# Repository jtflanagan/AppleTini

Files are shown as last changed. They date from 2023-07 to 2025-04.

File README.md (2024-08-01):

# AppleTini
An FPGA-based multifunctional card

Earlier iterations of the design used microcontrollers (a Pico and a Teensy 4.1), but we have moved to an FPGA-based design.  The v4 version of the board works in an Apple IIe as a read-only bus dump card.  It reads events on the Apple II bus, and forwards them over USB to a remote host which can process them (including operating as HDMI video-out, similar to the VidHD card).

The v5 board (just ordered!) is intended to provide the full bus feature set.  The ability to read and write data to the bus, as well as perform full DMA and assert all the control lines available (DMA, RES, RDY, INH, IRQ, NMI, and properly implement DMAIN/OUT and INTIN/OUT.

The boards are designed to connect to a stack of Alchitry boards as sold by SparkFun.  The boards have headers which will mate with the Alchitry Br breakout board.  The high-speed USB needed to do bus dumping is provided by the Alchitry Ft board, which is capable of up to 1.6Gbits/sec data transmit over USB3.  The FPGA, and 256MB of DDR3 SDRAM is provided by the Alchitry Au board.

What can this board ultimately do?  Damn near anything.  Shorter term goals are to provide HDMI out, speaker sound, Mockingboard sound, mouse, Ramworks or Slinky style memory expansion, and solid state HDV storage.  Longer term?  CPU Acceleration.  In-circuit Emulator level debugging.  More flexible expanded memory banking techniques.  There's a lot of potential!  The FPGA on the Alchitry Au is an Artix-7 35T, so there's a lot of room for all kinds of stuff.

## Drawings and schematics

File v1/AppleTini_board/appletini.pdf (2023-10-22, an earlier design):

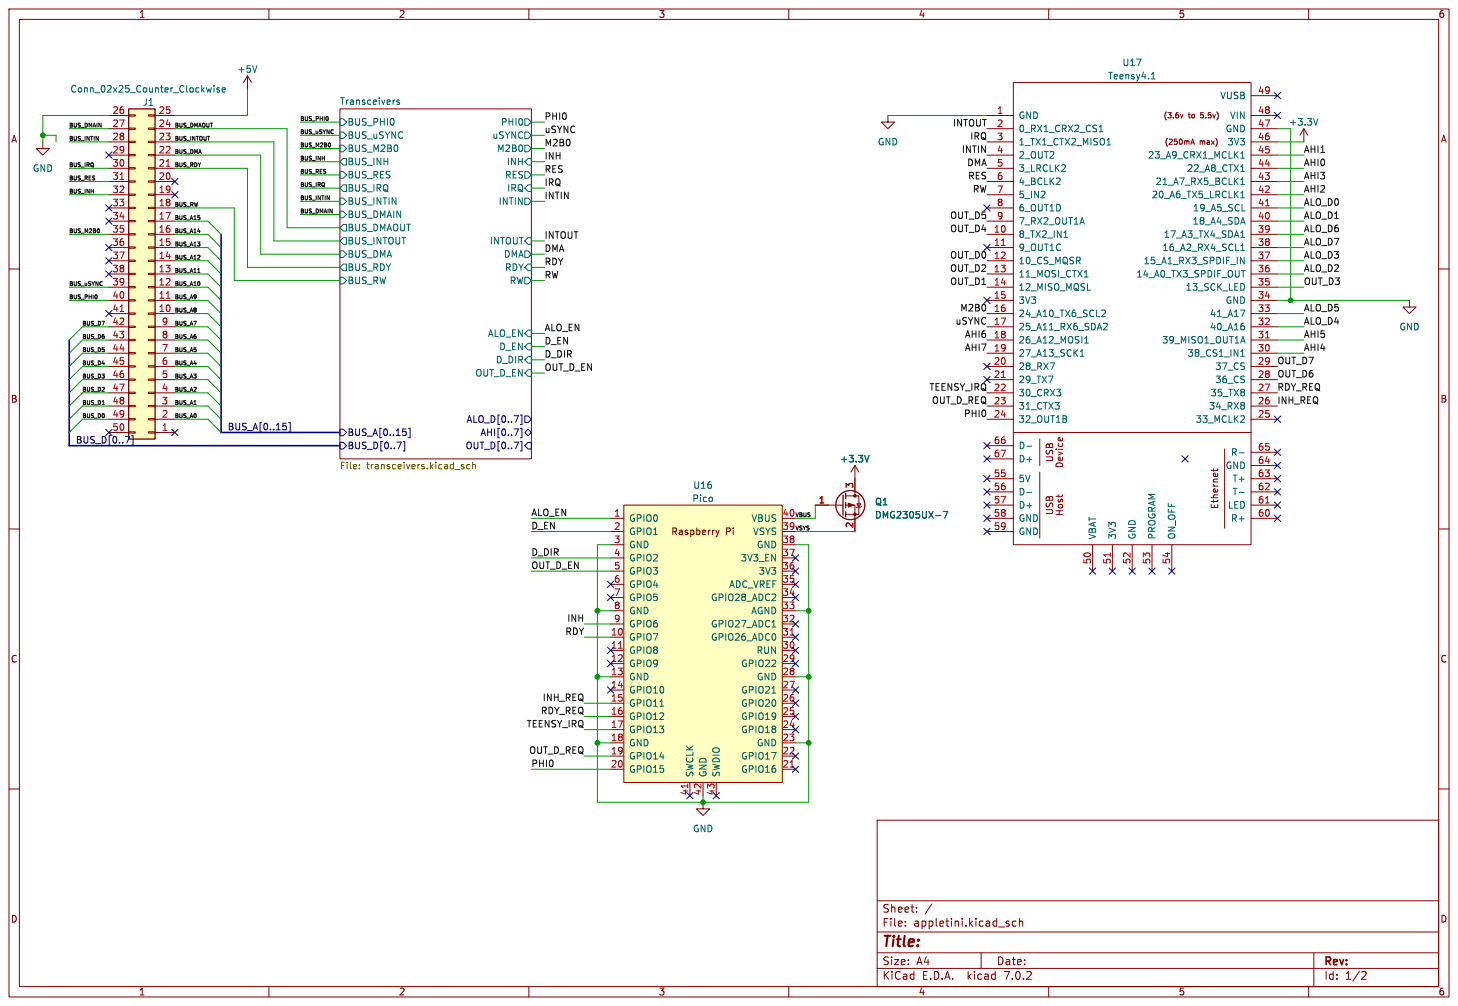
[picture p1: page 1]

Id: 1/2 Title: File: appletini.kicad_sch Sheet: /

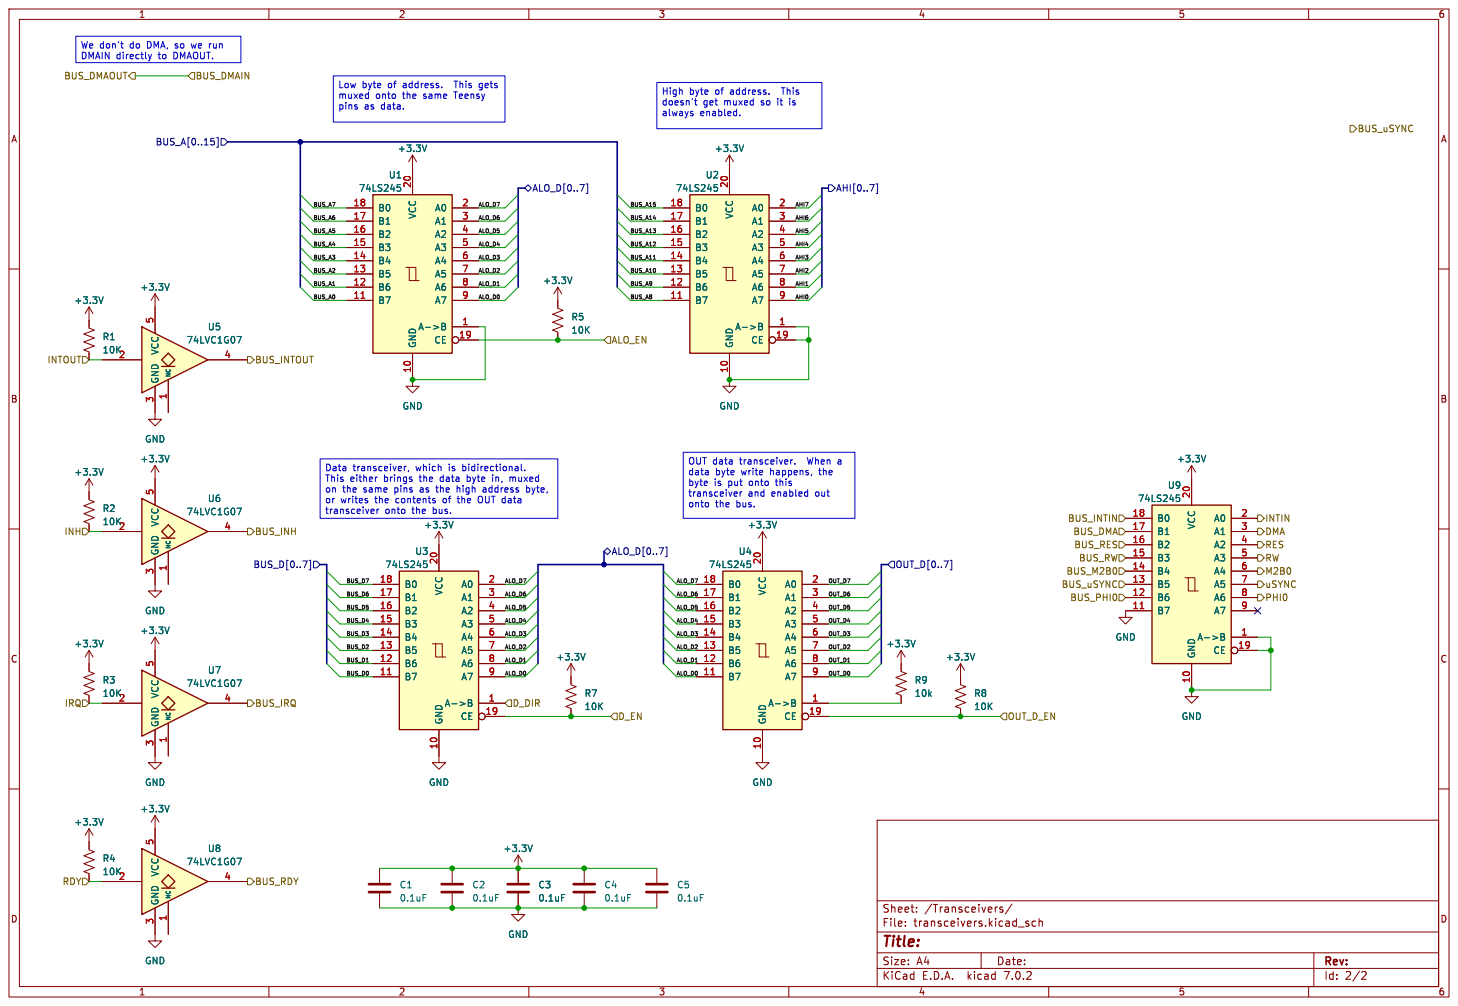
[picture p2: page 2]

data byte write happens, the
byte is put onto this

Id: 2/2 Title: File: transceivers.kicad_sch Sheet: /Transceivers/ R7

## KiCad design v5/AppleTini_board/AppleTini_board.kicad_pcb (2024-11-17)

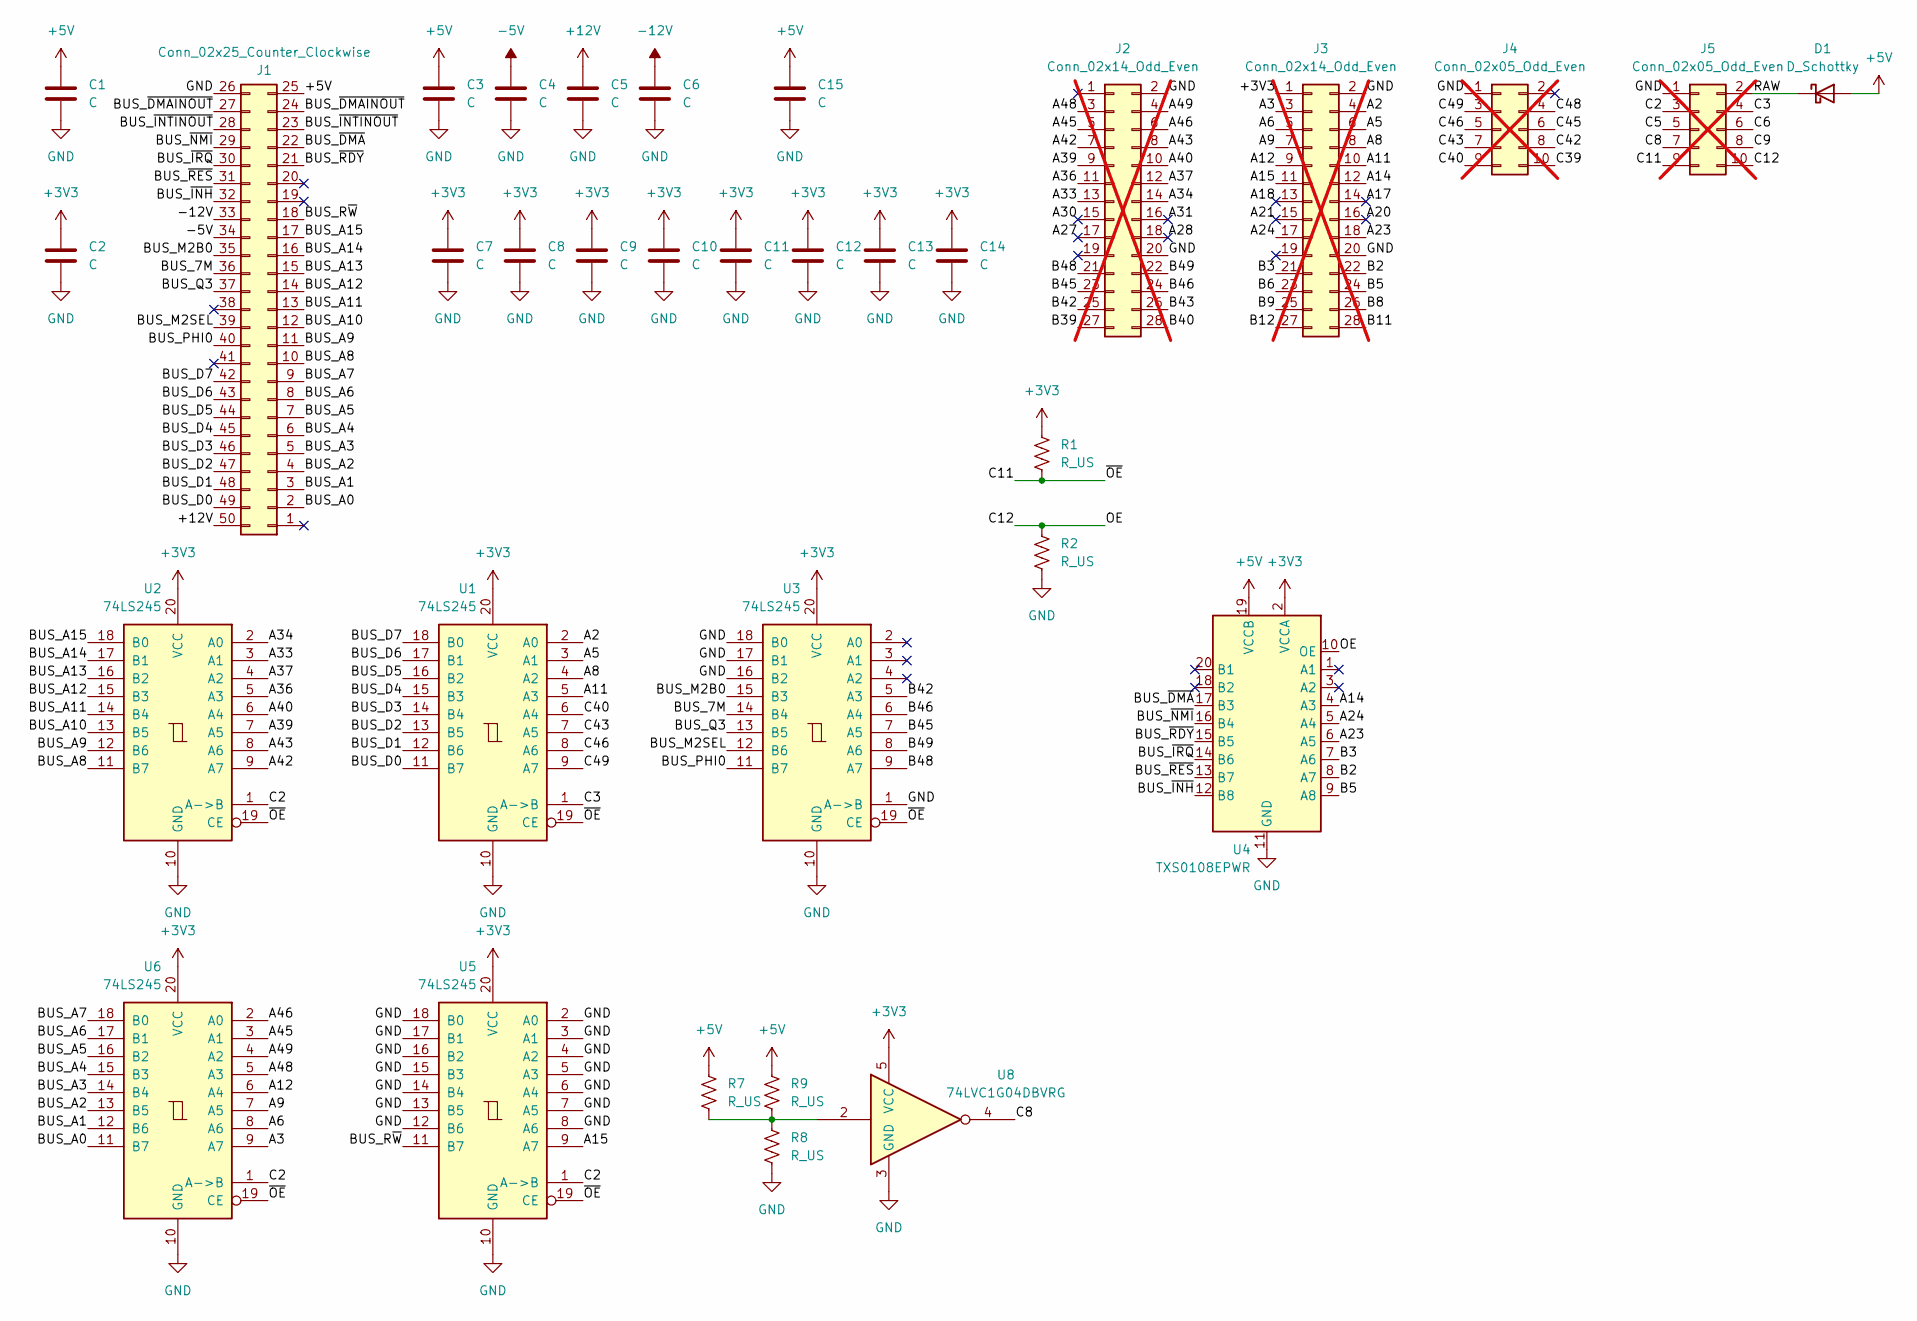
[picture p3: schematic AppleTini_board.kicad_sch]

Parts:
C1, C2: C; C_0805_2012Metric; LCSC C440198
C3, C4, C5, C6, C7, C8, C9, C10, C11, C12, C13, C14, C15: C; C_0402_1005Metric; LCSC C77020
D1: D_Schottky; Nexperia_CFP3_SOD-123W; LCSC C82288
J1: Conn_02x25_Counter_Clockwise; AppleIIBus_Edge
J2, J3: Conn_02x14_Odd_Even; PinHeader_2x14_P2.54mm_Vertical; not fitted
J4, J5: Conn_02x05_Odd_Even; PinHeader_2x05_P2.54mm_Vertical; not fitted
R1, R2, R7, R8, R9: R_US; R_0402_1005Metric; LCSC C2991755
U1, U2, U3, U5, U6: 74LS245; TSSOP-20_4.4x6.5mm_P0.65mm; LCSC C6082
U4: TXS0108EPWR; TSSOP-20_4.4x6.5mm_P0.65mm; LCSC C17206
U8: 74LVC1G04DBVRG; SOT-23-5

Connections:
+3V3: C2.1, C7.1, C8.1, C9.1, C10.1, C11.1, C12.1, C13.1, C14.1, J3.1, R1.1, U1.20 (VCC), U2.20 (VCC), U3.20 (VCC), U4.2 (VCCA), U5.20 (VCC), U6.20 (VCC), U8.5 (VCC)
+5V: C1.1, C3.1, C15.1, D1.2 (A), J1.25, R7.1, R9.1, U4.19 (VCCB)
+12V: C5.1, J1.50
-5V: C4.1, J1.34
-12V: C6.1, J1.33
/A2: J3.4, U1.2 (A0)
/A3: J3.3, U6.9 (A7)
/A5: J3.6, U1.3 (A1)
/A6: J3.5, U6.8 (A6)
/A8: J3.8, U1.4 (A2)
/A9: J3.7, U6.7 (A5)
/A11: J3.10, U1.5 (A3)
/A12: J3.9, U6.6 (A4)
/A14: J3.12, U4.4 (A3)
/A15: J3.11, U5.9 (A7)
/A17: J3.14
/A18: J3.13
/A20: J3.16
/A21: J3.15
/A23: J3.18, U4.6 (A5)
/A24: J3.17, U4.5 (A4)
/A27: J2.17
/A28: J2.18
/A30: J2.15
/A31: J2.16
/A33: J2.13, U2.3 (A1)
/A34: J2.14, U2.2 (A0)
/A36: J2.11, U2.5 (A3)
/A37: J2.12, U2.4 (A2)
/A39: J2.9, U2.7 (A5)
/A40: J2.10, U2.6 (A4)
/A42: J2.7, U2.9 (A7)
/A43: J2.8, U2.8 (A6)
/A45: J2.5, U6.3 (A1)
/A46: J2.6, U6.2 (A0)
/A48: J2.3, U6.5 (A3)
/A49: J2.4, U6.4 (A2)
/B2: J3.22, U4.8 (A7)
/B3: J3.21, U4.7 (A6)
/B5: J3.24, U4.9 (A8)
/B6: J3.23
/B8: J3.26
/B9: J3.25
/B11: J3.28
/B12: J3.27
/B39: J2.27
/B40: J2.28
/B42: J2.25, U3.5 (A3)
/B43: J2.26
/B45: J2.23, U3.7 (A5)
/B46: J2.24, U3.6 (A4)
/B48: J2.21, U3.9 (A7)
/B49: J2.22, U3.8 (A6)
/BUS_7M: J1.36, U3.14 (B4)
/BUS_A0: J1.2, U6.11 (B7)
/BUS_A1: J1.3, U6.12 (B6)
/BUS_A2: J1.4, U6.13 (B5)
/BUS_A3: J1.5, U6.14 (B4)
/BUS_A4: J1.6, U6.15 (B3)
/BUS_A5: J1.7, U6.16 (B2)
/BUS_A6: J1.8, U6.17 (B1)
/BUS_A7: J1.9, U6.18 (B0)
/BUS_A8: J1.10, U2.11 (B7)
/BUS_A9: J1.11, U2.12 (B6)
/BUS_A10: J1.12, U2.13 (B5)
/BUS_A11: J1.13, U2.14 (B4)
/BUS_A12: J1.14, U2.15 (B3)
/BUS_A13: J1.15, U2.16 (B2)
/BUS_A14: J1.16, U2.17 (B1)
/BUS_A15: J1.17, U2.18 (B0)
/BUS_D0: J1.49, U1.11 (B7)
/BUS_D1: J1.48, U1.12 (B6)
/BUS_D2: J1.47, U1.13 (B5)
/BUS_D3: J1.46, U1.14 (B4)
/BUS_D4: J1.45, U1.15 (B3)
/BUS_D5: J1.44, U1.16 (B2)
/BUS_D6: J1.43, U1.17 (B1)
/BUS_D7: J1.42, U1.18 (B0)
/BUS_M2B0: J1.35, U3.15 (B3)
/BUS_M2SEL: J1.39, U3.12 (B6)
/BUS_PHI0: J1.40, U3.11 (B7)
/BUS_Q3: J1.37, U3.13 (B5)
/BUS_R~W: J1.18, U5.11 (B7)
/BUS_~DMAINOUT: J1.24, J1.27
/BUS_~DMA: J1.22, U4.17 (B3)
/BUS_~INH: J1.32, U4.12 (B8)
/BUS_~INTINOUT: J1.23, J1.28
/BUS_~IRQ: J1.30, U4.14 (B6)
/BUS_~NMI: J1.29, U4.16 (B4)
/BUS_~RDY: J1.21, U4.15 (B5)
/BUS_~RES: J1.31, U4.13 (B7)
/C2: J5.3, U2.1 (A->B), U5.1 (A->B), U6.1 (A->B)
/C3: J5.4, U1.1 (A->B)
/C5: J5.5
/C6: J5.6
/C8: J5.7, U8.4
/C9: J5.8
/C11: J5.9, R1.2, U1.19 (CE), U2.19 (CE), U3.19 (CE), U5.19 (CE), U6.19 (CE)
/C12: J5.10, R2.1, U4.10 (OE)
/C39: J4.10
/C40: J4.9, U1.6 (A4)
/C42: J4.8
/C43: J4.7, U1.7 (A5)
/C45: J4.6
/C46: J4.5, U1.8 (A6)
/C48: J4.4
/C49: J4.3, U1.9 (A7)
/RAW: D1.1 (K), J5.2
GND: C1.2, C2.2, C3.2, C4.2, C5.2, C6.2, C7.2, C8.2, C9.2, C10.2, C11.2, C12.2, C13.2, C14.2, C15.2, J1.26, J2.2, J2.20, J3.2, J3.20, J4.1, J5.1, R2.2, R8.2, U1.10 (GND), U2.10 (GND), U3.1 (A->B), U3.10 (GND), U3.16 (B2), U3.17 (B1), U3.18 (B0), U4.11 (GND), U5.2 (A0), U5.3 (A1), U5.4 (A2), U5.5 (A3), U5.6 (A4), U5.7 (A5), U5.8 (A6), U5.10 (GND), U5.12 (B6), U5.13 (B5), U5.14 (B4), U5.15 (B3), U5.16 (B2), U5.17 (B1), U5.18 (B0), U6.10 (GND), U8.3 (GND)
unnamed: R7.2, R8.1, R9.2, U8.2

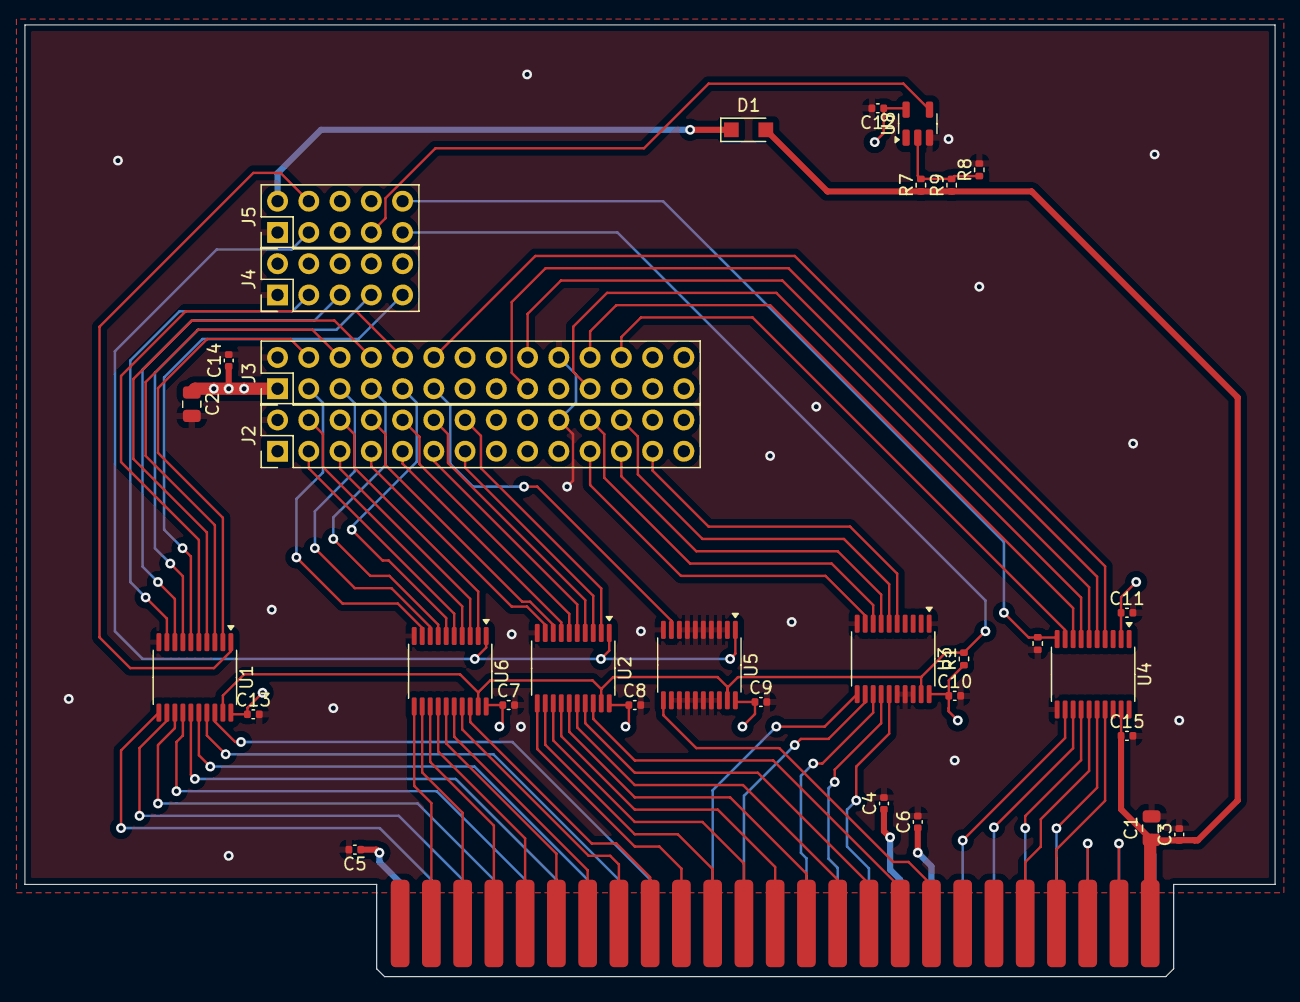
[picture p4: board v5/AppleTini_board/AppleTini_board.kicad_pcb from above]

Board: 4 copper layers, 101.6 x 77.3 mm, 33 parts (0 on the bottom side), 87 nets.

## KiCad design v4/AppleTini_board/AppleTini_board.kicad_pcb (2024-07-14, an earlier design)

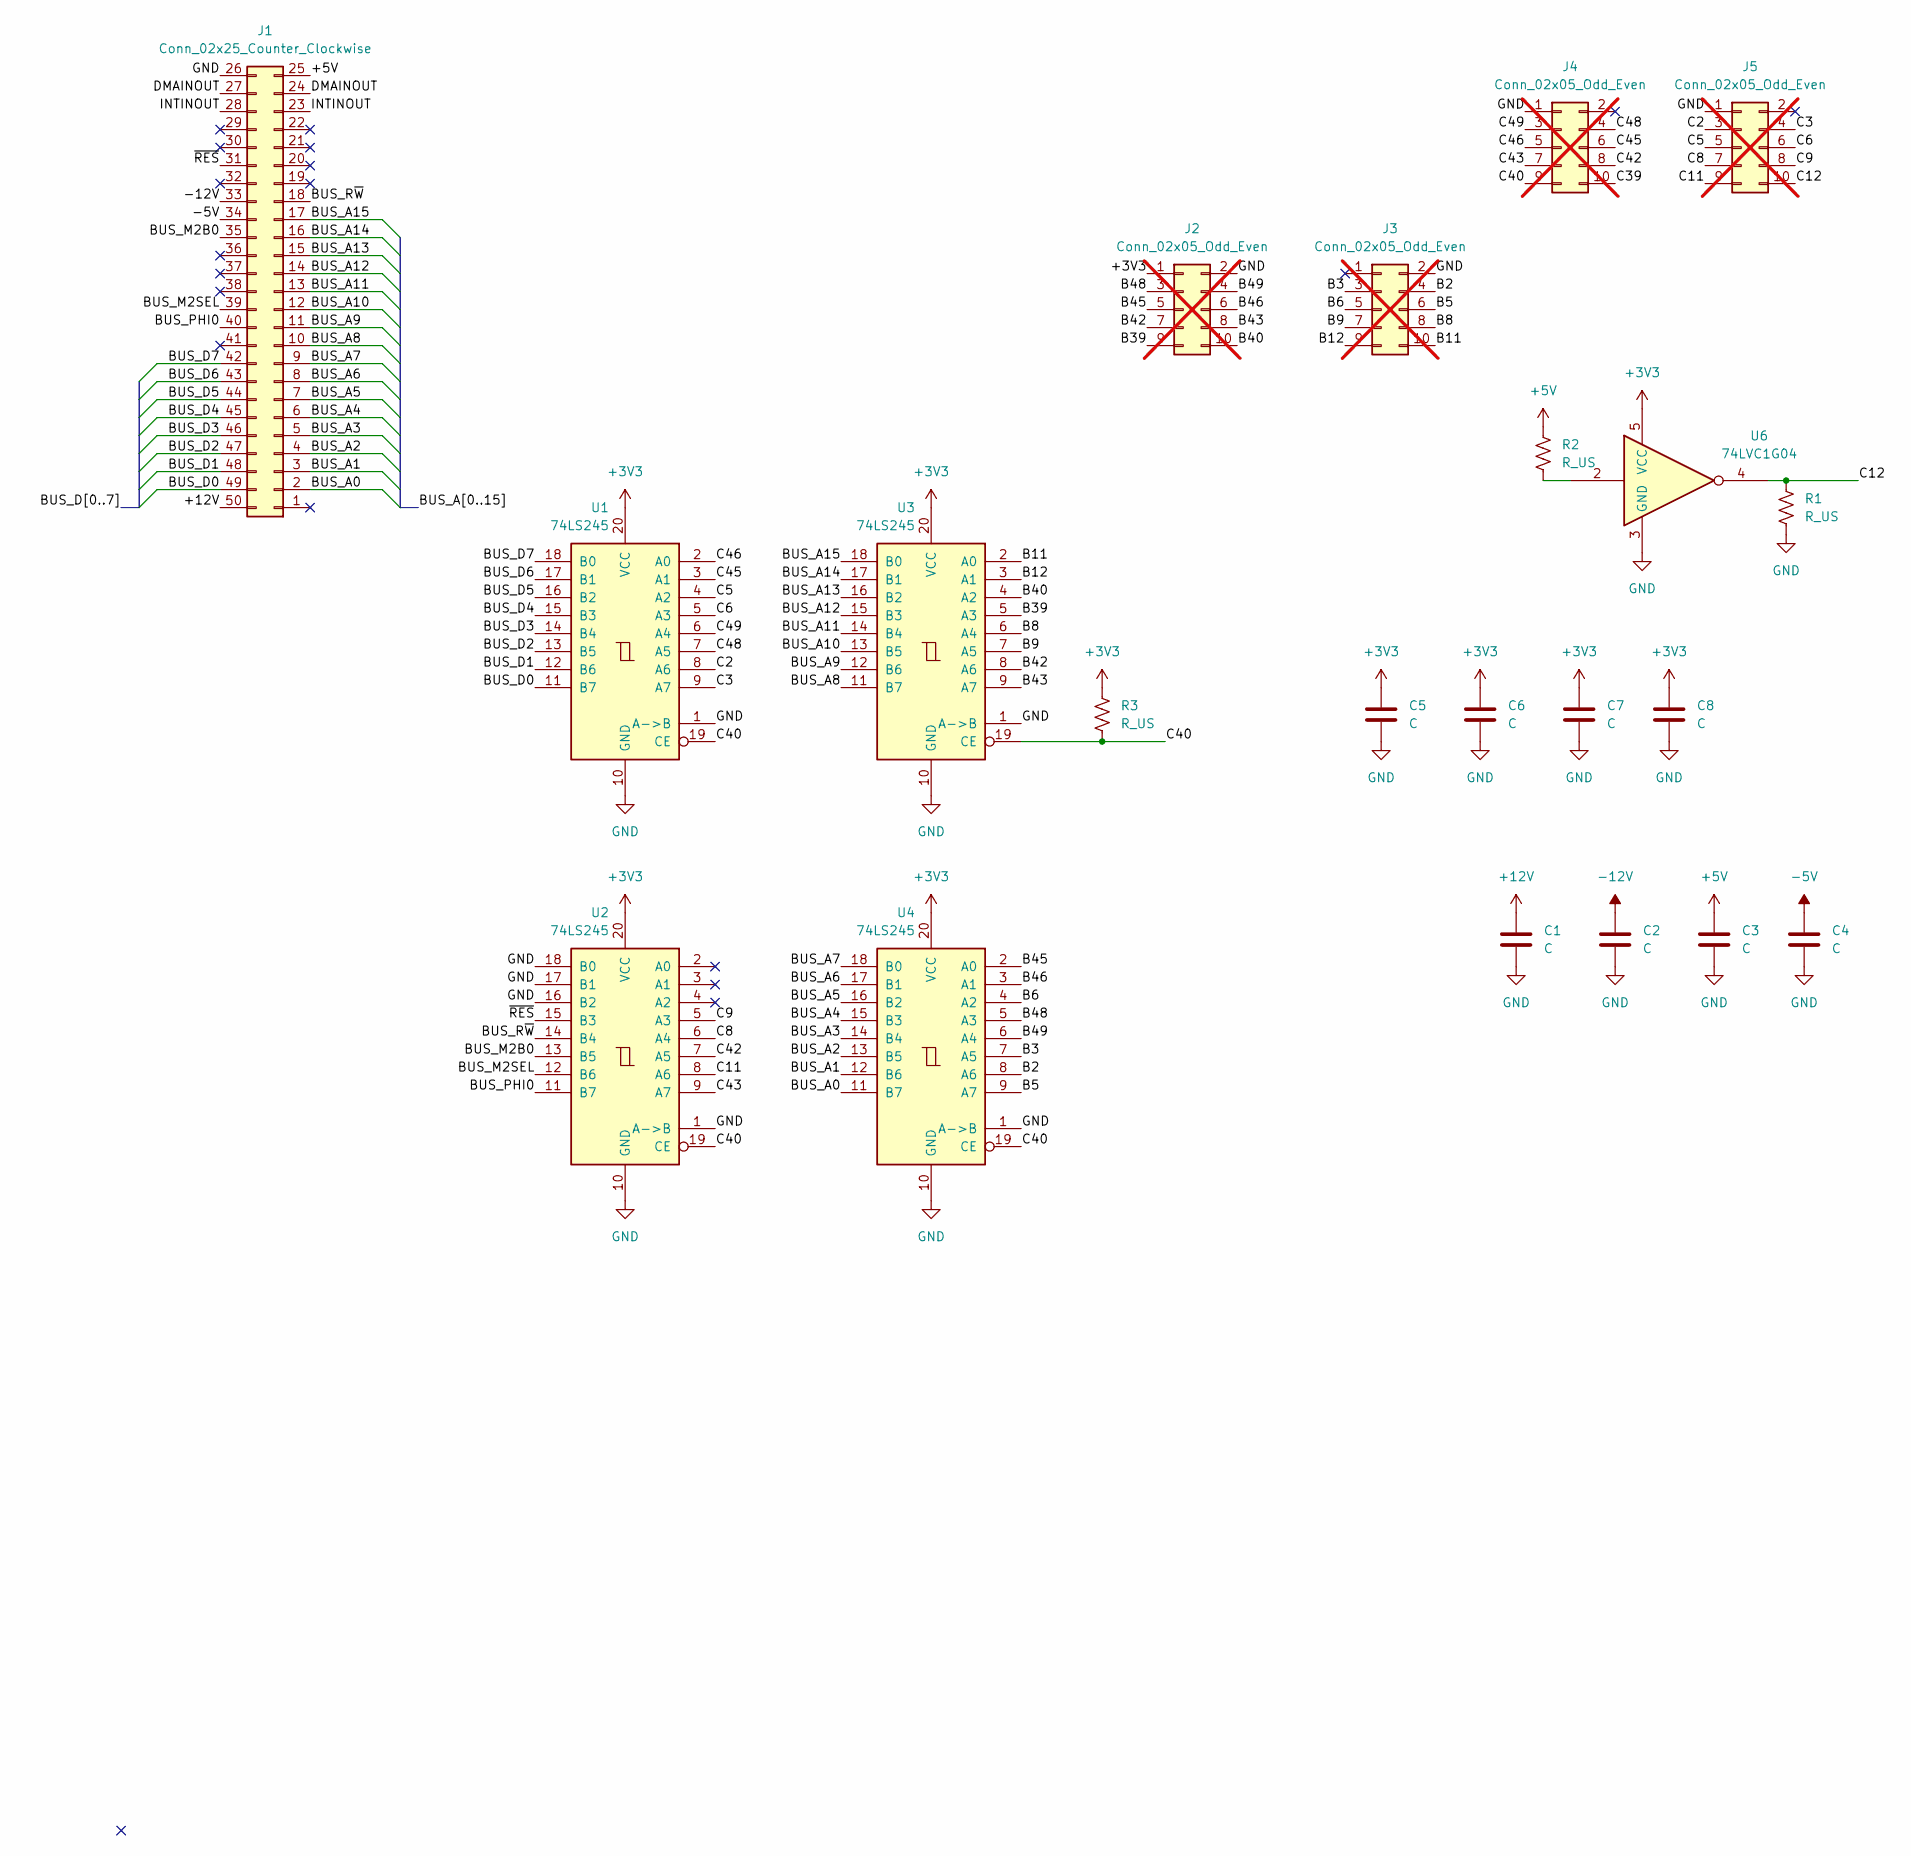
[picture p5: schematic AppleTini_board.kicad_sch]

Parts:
C1, C2, C3, C4, C5, C6, C7, C8: C; C_1206_3216Metric; LCSC C24497
J1: Conn_02x25_Counter_Clockwise; AppleIIBus_Edge
J2, J3, J4, J5: Conn_02x05_Odd_Even; PinHeader_2x05_P2.54mm_Vertical; not fitted
R1, R2, R3: R_US; C_0402_1005Metric; LCSC C2991755
U1, U2, U3, U4: 74LS245; TSSOP-20_4.4x6.5mm_P0.65mm; LCSC C6082
U6: 74LVC1G04; SOT-23-5; LCSC C7826

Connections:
+3V3: C5.1, C6.1, C7.1, C8.1, J2.1, R3.1, U1.20 (VCC), U2.20 (VCC), U3.20 (VCC), U4.20 (VCC), U6.5 (VCC)
+5V: C3.1, J1.25, R2.1
+12V: C1.1, J1.50
-5V: C4.1, J1.34
-12V: C2.1, J1.33
/B2: J3.4, U4.8 (A6)
/B3: J3.3, U4.7 (A5)
/B5: J3.6, U4.9 (A7)
/B6: J3.5, U4.4 (A2)
/B8: J3.8, U3.6 (A4)
/B9: J3.7, U3.7 (A5)
/B11: J3.10, U3.2 (A0)
/B12: J3.9, U3.3 (A1)
/B39: J2.9, U3.5 (A3)
/B40: J2.10, U3.4 (A2)
/B42: J2.7, U3.8 (A6)
/B43: J2.8, U3.9 (A7)
/B45: J2.5, U4.2 (A0)
/B46: J2.6, U4.3 (A1)
/B48: J2.3, U4.5 (A3)
/B49: J2.4, U4.6 (A4)
/BUS_A0: J1.2, U4.11 (B7)
/BUS_A1: J1.3, U4.12 (B6)
/BUS_A2: J1.4, U4.13 (B5)
/BUS_A3: J1.5, U4.14 (B4)
/BUS_A4: J1.6, U4.15 (B3)
/BUS_A5: J1.7, U4.16 (B2)
/BUS_A6: J1.8, U4.17 (B1)
/BUS_A7: J1.9, U4.18 (B0)
/BUS_A8: J1.10, U3.11 (B7)
/BUS_A9: J1.11, U3.12 (B6)
/BUS_A10: J1.12, U3.13 (B5)
/BUS_A11: J1.13, U3.14 (B4)
/BUS_A12: J1.14, U3.15 (B3)
/BUS_A13: J1.15, U3.16 (B2)
/BUS_A14: J1.16, U3.17 (B1)
/BUS_A15: J1.17, U3.18 (B0)
/BUS_D0: J1.49, U1.11 (B7)
/BUS_D1: J1.48, U1.12 (B6)
/BUS_D2: J1.47, U1.13 (B5)
/BUS_D3: J1.46, U1.14 (B4)
/BUS_D4: J1.45, U1.15 (B3)
/BUS_D5: J1.44, U1.16 (B2)
/BUS_D6: J1.43, U1.17 (B1)
/BUS_D7: J1.42, U1.18 (B0)
/BUS_M2B0: J1.35, U2.13 (B5)
/BUS_M2SEL: J1.39, U2.12 (B6)
/BUS_PHI0: J1.40, U2.11 (B7)
/BUS_R~W: J1.18, U2.14 (B4)
/C2: J5.3, U1.8 (A6)
/C3: J5.4, U1.9 (A7)
/C5: J5.5, U1.4 (A2)
/C6: J5.6, U1.5 (A3)
/C8: J5.7, U2.6 (A4)
/C9: J5.8, U2.5 (A3)
/C11: J5.9, U2.8 (A6)
/C12: J5.10, R1.1, U6.4
/C39: J4.10
/C40: J4.9, R3.2, U1.19 (CE), U2.19 (CE), U3.19 (CE), U4.19 (CE)
/C42: J4.8, U2.7 (A5)
/C43: J4.7, U2.9 (A7)
/C45: J4.6, U1.3 (A1)
/C46: J4.5, U1.2 (A0)
/C48: J4.4, U1.7 (A5)
/C49: J4.3, U1.6 (A4)
/DMAINOUT: J1.24, J1.27
/INTINOUT: J1.23, J1.28
/~RES: J1.31, U2.15 (B3)
GND: C1.2, C2.2, C3.2, C4.2, C5.2, C6.2, C7.2, C8.2, J1.26, J2.2, J3.2, J4.1, J5.1, R1.2, U1.1 (A->B), U1.10 (GND), U2.1 (A->B), U2.10 (GND), U2.16 (B2), U2.17 (B1), U2.18 (B0), U3.1 (A->B), U3.10 (GND), U4.1 (A->B), U4.10 (GND), U6.3 (GND)
unnamed: R2.2, U6.2

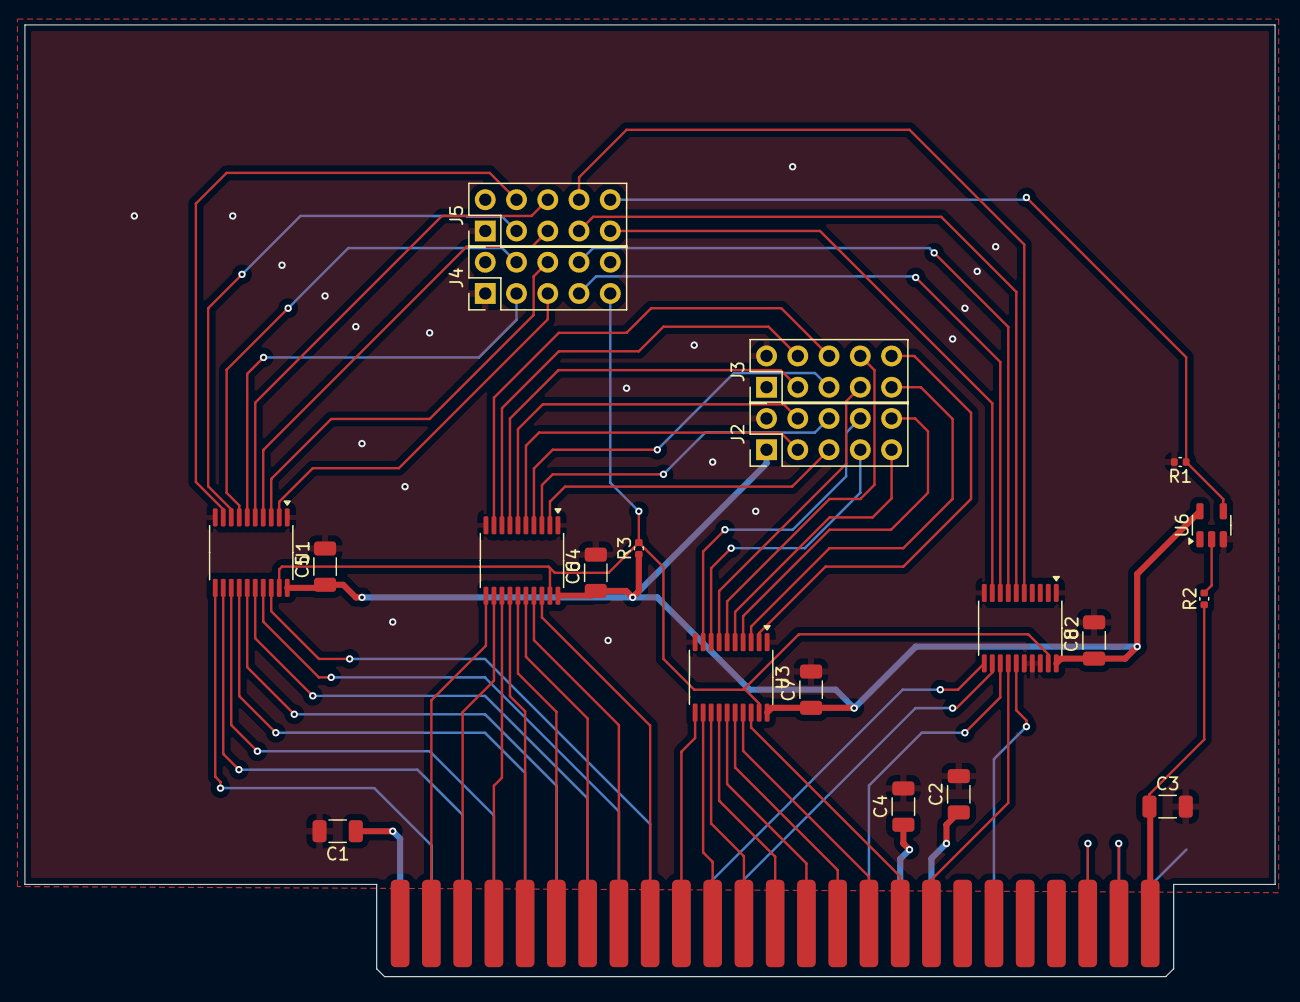
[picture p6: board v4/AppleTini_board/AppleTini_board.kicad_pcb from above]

Board: 2 copper layers, 101.6 x 77.3 mm, 21 parts (0 on the bottom side), 69 nets.

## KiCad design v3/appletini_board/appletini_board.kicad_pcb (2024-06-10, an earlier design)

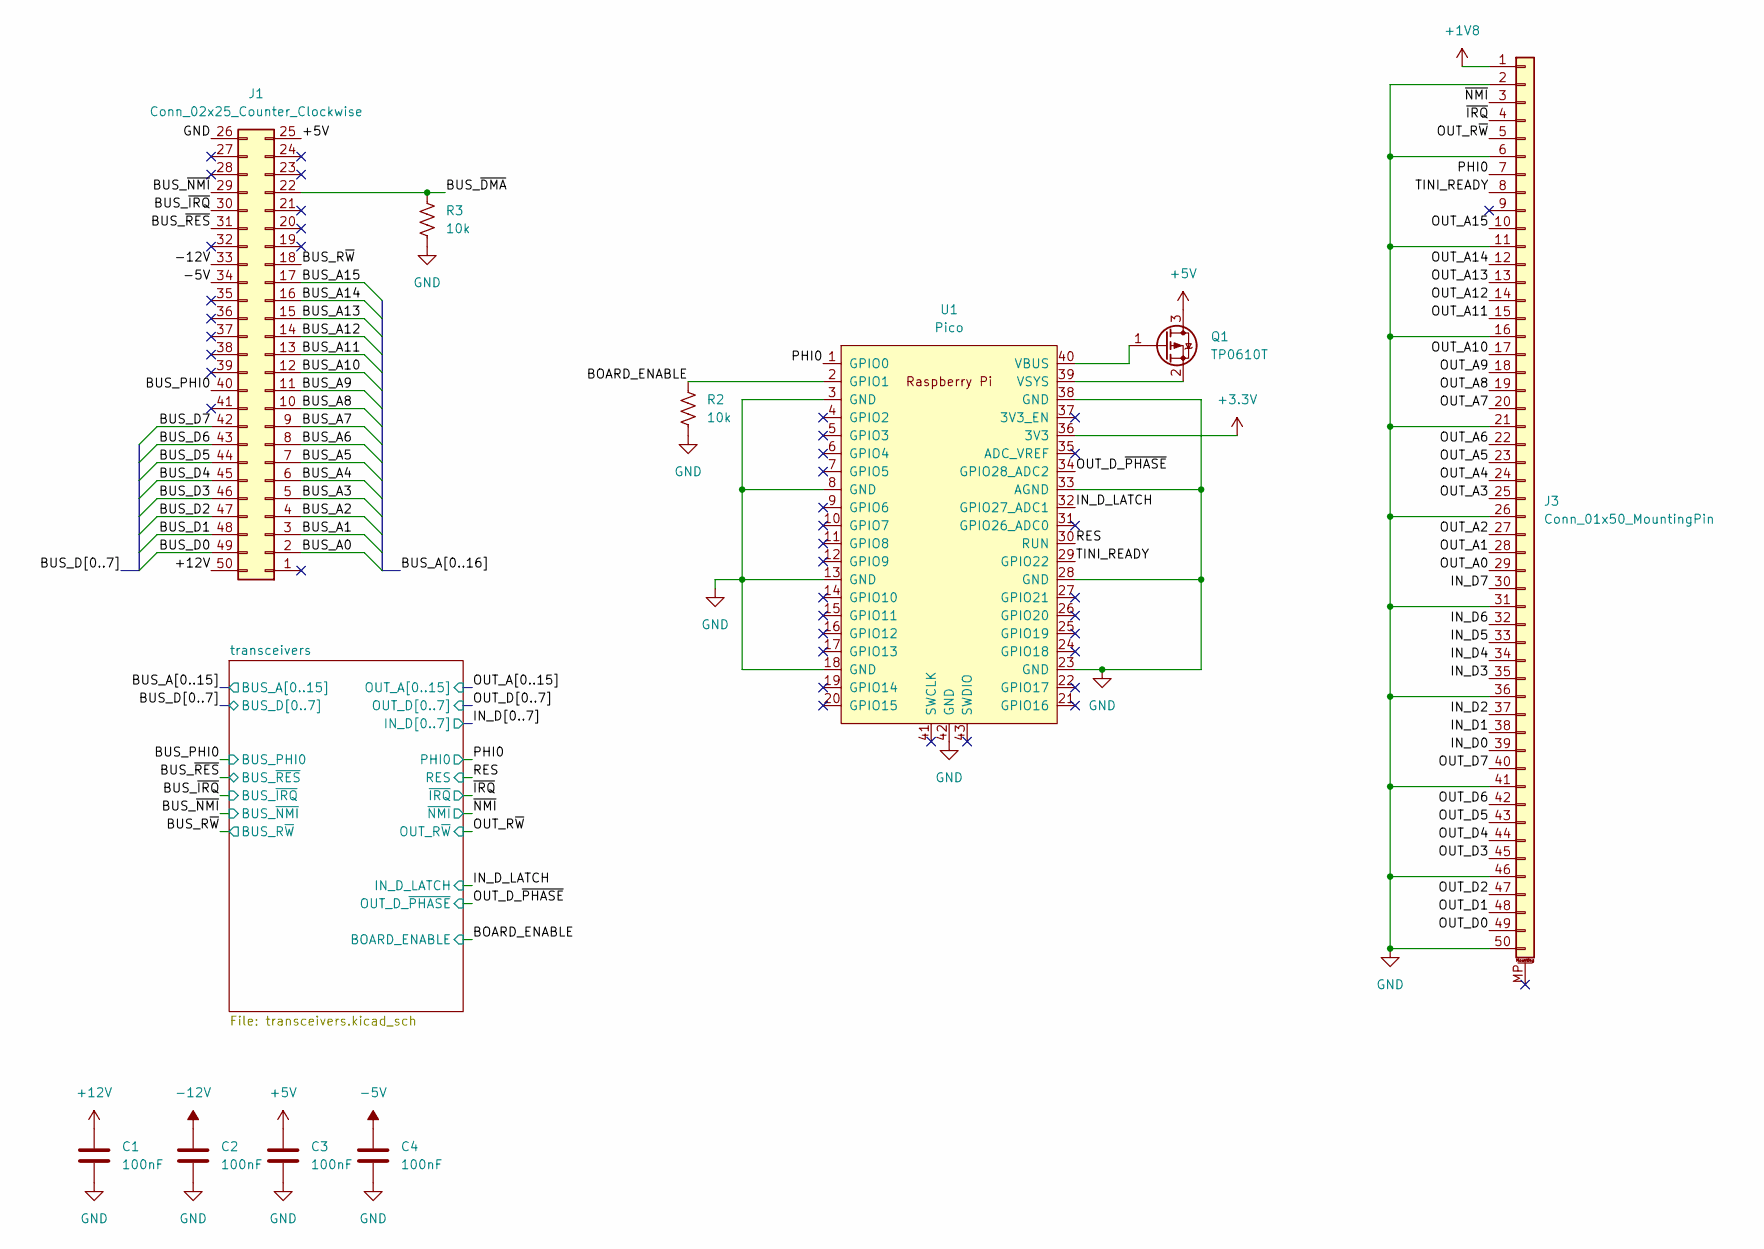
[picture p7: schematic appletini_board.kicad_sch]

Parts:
C1, C2, C3, C4: 100nF; C_1206_3216Metric; LCSC C24497
J1: Conn_02x25_Counter_Clockwise; AppleIIBus_Edge
J3: Conn_01x50_MountingPin; Hirose_FH12-50S-0.5SH_1x50-1MP_P0.50mm_Horizontal; LCSC C202116
Q1: TP0610T; SOT-23; LCSC C5261054
R2, R3: 10k; R_0402_1005Metric; LCSC C2991755
U1: Pico; RPi_Pico_SMD_TH; LCSC C7203002

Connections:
+1V8: J3.1; also elsewhere on the board
+3.3V: U1.36 (3V3); also elsewhere on the board
+5V: C3.1, J1.25, Q1.3 (D); also elsewhere on the board
+12V: C1.1, J1.50
-5V: C4.1, J1.34
-12V: C2.1, J1.33
/BOARD_ENABLE: R2.1, U1.2 (GPIO1); also elsewhere on the board
/BUS_A0: J1.2; also elsewhere on the board
/BUS_A1: J1.3; also elsewhere on the board
/BUS_A2: J1.4; also elsewhere on the board
/BUS_A3: J1.5; also elsewhere on the board
/BUS_A4: J1.6; also elsewhere on the board
/BUS_A5: J1.7; also elsewhere on the board
/BUS_A6: J1.8; also elsewhere on the board
/BUS_A7: J1.9; also elsewhere on the board
/BUS_A8: J1.10; also elsewhere on the board
/BUS_A9: J1.11; also elsewhere on the board
/BUS_A10: J1.12; also elsewhere on the board
/BUS_A11: J1.13; also elsewhere on the board
/BUS_A12: J1.14; also elsewhere on the board
/BUS_A13: J1.15; also elsewhere on the board
/BUS_A14: J1.16; also elsewhere on the board
/BUS_A15: J1.17; also elsewhere on the board
/BUS_D0: J1.49; also elsewhere on the board
/BUS_D1: J1.48; also elsewhere on the board
/BUS_D2: J1.47; also elsewhere on the board
/BUS_D3: J1.46; also elsewhere on the board
/BUS_D4: J1.45; also elsewhere on the board
/BUS_D5: J1.44; also elsewhere on the board
/BUS_D6: J1.43; also elsewhere on the board
/BUS_D7: J1.42; also elsewhere on the board
/BUS_PHI0: J1.40; also elsewhere on the board
/BUS_R~W: J1.18; also elsewhere on the board
/BUS_~DMA: J1.22, R3.1
/BUS_~IRQ: J1.30; also elsewhere on the board
/BUS_~NMI: J1.29; also elsewhere on the board
/BUS_~RES: J1.31; also elsewhere on the board
/IN_D0: J3.39; also elsewhere on the board
/IN_D1: J3.38; also elsewhere on the board
/IN_D2: J3.37; also elsewhere on the board
/IN_D3: J3.35; also elsewhere on the board
/IN_D4: J3.34; also elsewhere on the board
/IN_D5: J3.33; also elsewhere on the board
/IN_D6: J3.32; also elsewhere on the board
/IN_D7: J3.30; also elsewhere on the board
/IN_D_LATCH: U1.32 (GPIO27_ADC1); also elsewhere on the board
/OUT_A0: J3.29; also elsewhere on the board
/OUT_A1: J3.28; also elsewhere on the board
/OUT_A2: J3.27; also elsewhere on the board
/OUT_A3: J3.25; also elsewhere on the board
/OUT_A4: J3.24; also elsewhere on the board
/OUT_A5: J3.23; also elsewhere on the board
/OUT_A6: J3.22; also elsewhere on the board
/OUT_A7: J3.20; also elsewhere on the board
/OUT_A8: J3.19; also elsewhere on the board
/OUT_A9: J3.18; also elsewhere on the board
/OUT_A10: J3.17; also elsewhere on the board
/OUT_A11: J3.15; also elsewhere on the board
/OUT_A12: J3.14; also elsewhere on the board
/OUT_A13: J3.13; also elsewhere on the board
/OUT_A14: J3.12; also elsewhere on the board
/OUT_A15: J3.10; also elsewhere on the board
/OUT_D0: J3.49; also elsewhere on the board
/OUT_D1: J3.48; also elsewhere on the board
/OUT_D2: J3.47; also elsewhere on the board
/OUT_D3: J3.45; also elsewhere on the board
/OUT_D4: J3.44; also elsewhere on the board
/OUT_D5: J3.43; also elsewhere on the board
/OUT_D6: J3.42; also elsewhere on the board
/OUT_D7: J3.40; also elsewhere on the board
/OUT_D_~PHASE: U1.34 (GPIO28_ADC2); also elsewhere on the board
/OUT_R~W: J3.5; also elsewhere on the board
/PHI0: J3.7, U1.1 (GPIO0); also elsewhere on the board
/RES: U1.30 (RUN); also elsewhere on the board
/TINI_READY: J3.8, U1.29 (GPIO22)
/~IRQ: J3.4; also elsewhere on the board
/~NMI: J3.3; also elsewhere on the board
GND: C1.2, C2.2, C3.2, C4.2, J1.26, J3.2, J3.6, J3.11, J3.16, J3.21, J3.26, J3.31, J3.36, J3.41, J3.46, J3.50, R2.2, R3.2, U1.3 (GND), U1.8 (GND), U1.13 (GND), U1.18 (GND), U1.23 (GND), U1.28 (GND), U1.33 (AGND), U1.38 (GND), U1.42 (GND); also elsewhere on the board
unnamed: Q1.1 (G), U1.40 (VBUS)
unnamed: Q1.2 (S), U1.39 (VSYS)

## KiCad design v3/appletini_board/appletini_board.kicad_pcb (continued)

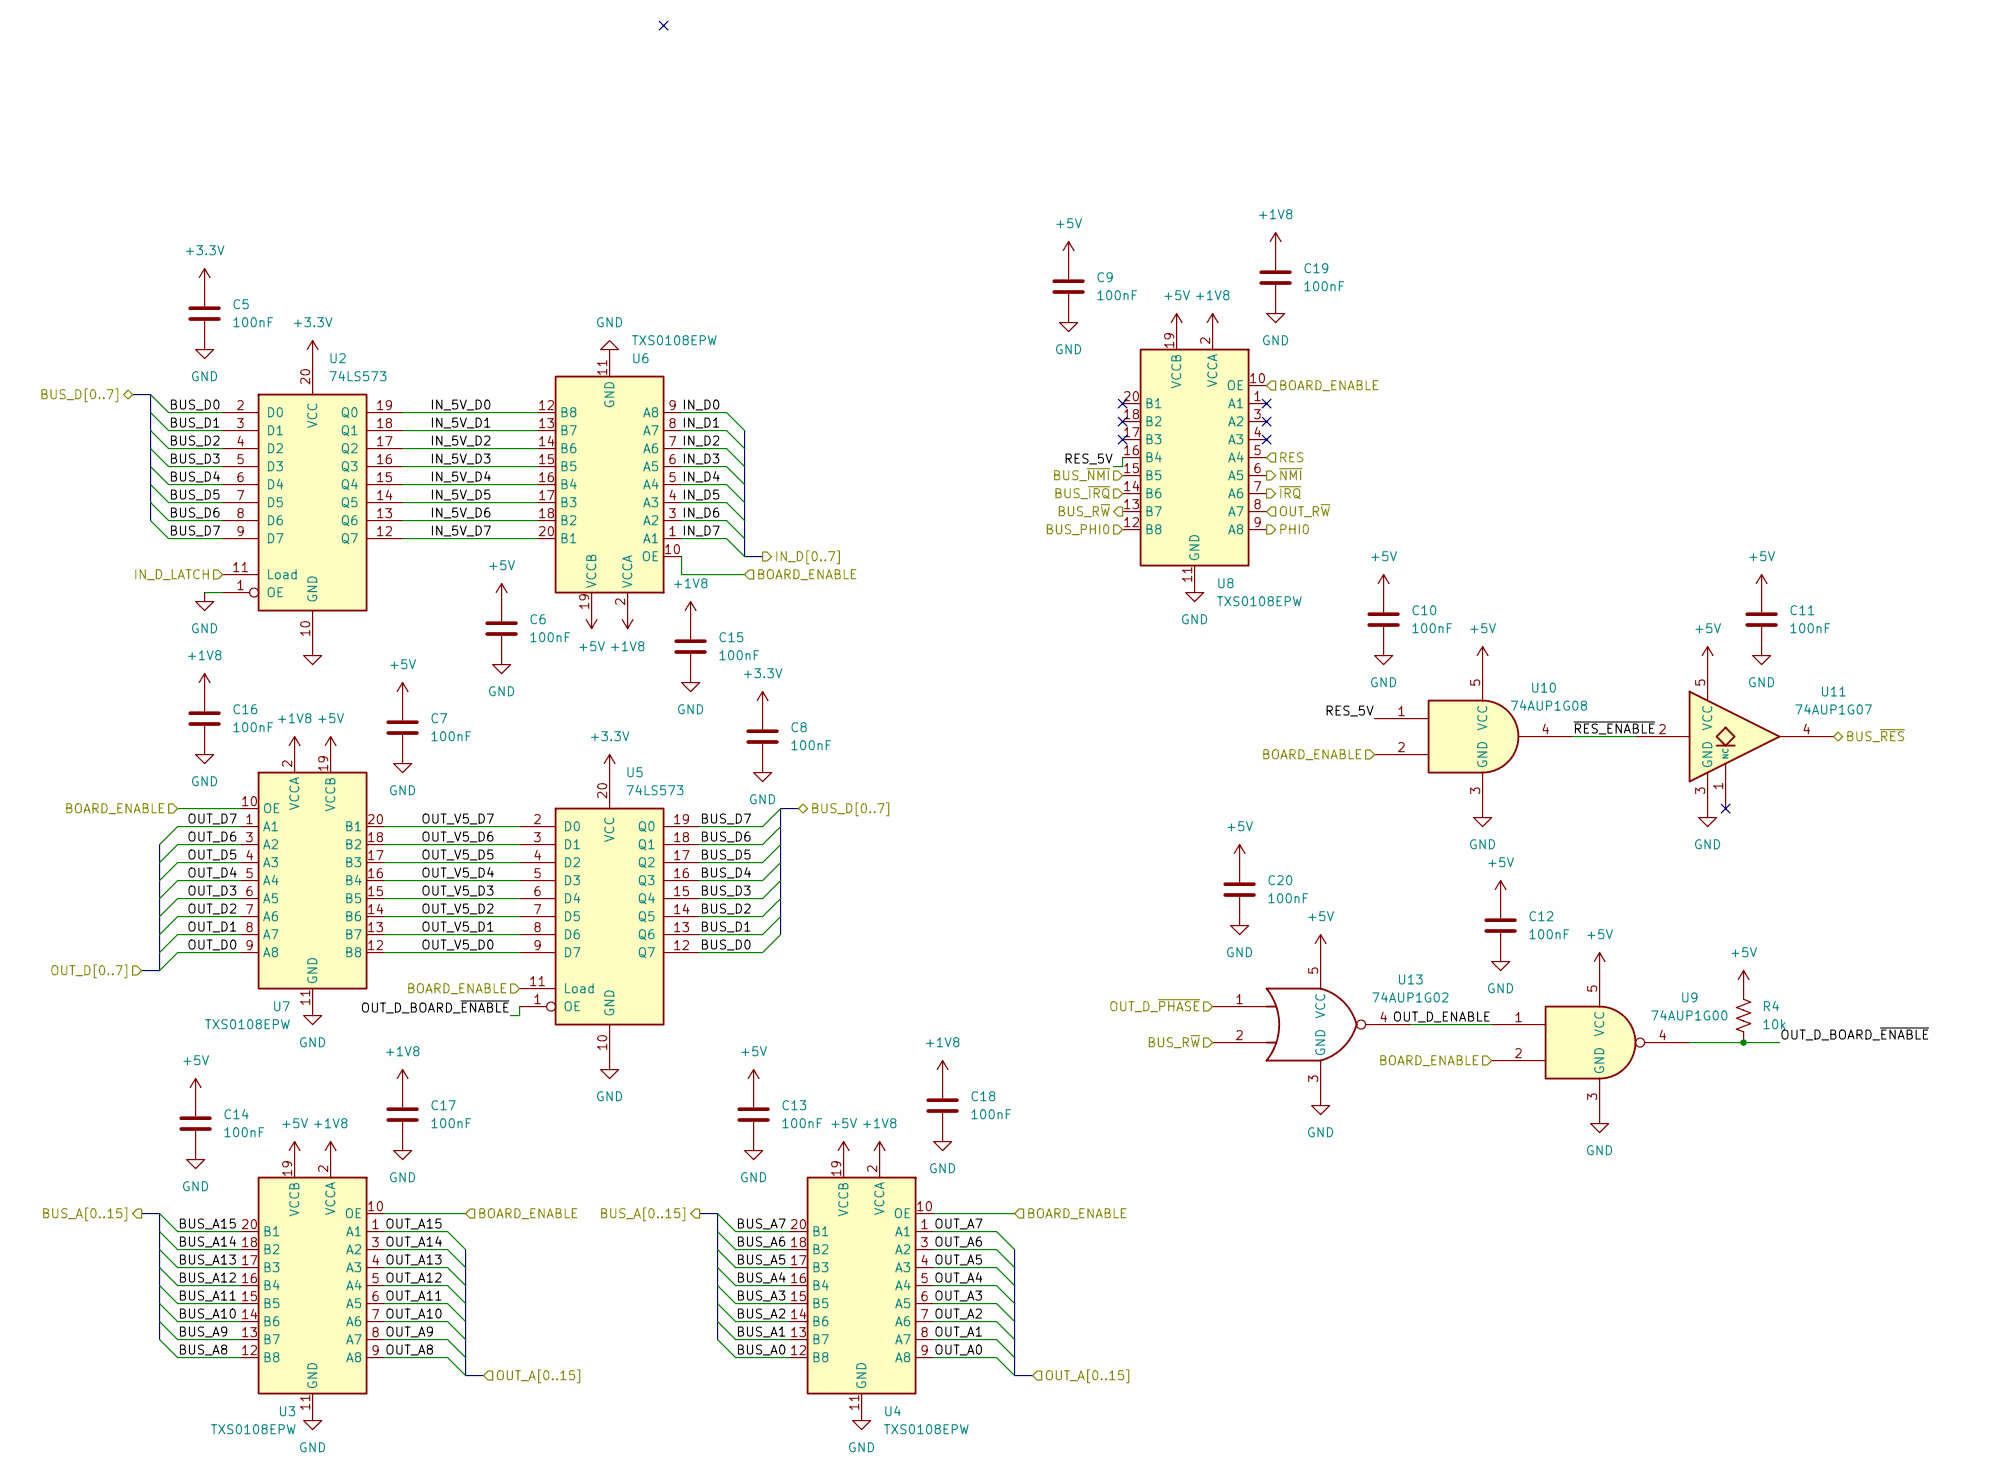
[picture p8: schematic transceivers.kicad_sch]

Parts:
C5, C6, C7, C8, C9, C10, C11, C12, C13, C14, C15, C16, C17, C18, C19, C20: 100nF; C_1206_3216Metric; LCSC C24497
R4: 10k; R_0402_1005Metric; LCSC C2991755
U2, U5: 74LS573; TSSOP-20_4.4x6.5mm_P0.65mm; LCSC C113280
U3, U4, U6, U7, U8: TXS0108EPW; TSSOP-20_4.4x6.5mm_P0.65mm; LCSC C17206
U9: 74AUP1G00; SOT-353_SC-70-5; LCSC C460514
U10: 74AUP1G08; SOT-353_SC-70-5; LCSC C233638
U11: 74AUP1G07; SOT-23-5; LCSC C242266
U13: 74AUP1G02; SOT-353_SC-70-5; LCSC C460515

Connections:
+1V8: C15.1, C16.1, C17.1, C18.1, C19.1, U3.2 (VCCA), U4.2 (VCCA), U6.2 (VCCA), U7.2 (VCCA), U8.2 (VCCA); also elsewhere on the board
+3.3V: C5.1, C8.1, U2.20 (VCC), U5.20 (VCC); also elsewhere on the board
+5V: C6.1, C7.1, C9.1, C10.1, C11.1, C12.1, C13.1, C14.1, C20.1, R4.1, U3.19 (VCCB), U4.19 (VCCB), U6.19 (VCCB), U7.19 (VCCB), U8.19 (VCCB), U9.5 (VCC), U10.5 (VCC), U11.5 (VCC), U13.5 (VCC); also elsewhere on the board
/BOARD_ENABLE: U3.10 (OE), U4.10 (OE), U5.11 (Load), U6.10 (OE), U7.10 (OE), U8.10 (OE), U9.2, U10.2; also elsewhere on the board
/BUS_A0: U4.12 (B8); also elsewhere on the board
/BUS_A1: U4.13 (B7); also elsewhere on the board
/BUS_A2: U4.14 (B6); also elsewhere on the board
/BUS_A3: U4.15 (B5); also elsewhere on the board
/BUS_A4: U4.16 (B4); also elsewhere on the board
/BUS_A5: U4.17 (B3); also elsewhere on the board
/BUS_A6: U4.18 (B2); also elsewhere on the board
/BUS_A7: U4.20 (B1); also elsewhere on the board
/BUS_A8: U3.12 (B8); also elsewhere on the board
/BUS_A9: U3.13 (B7); also elsewhere on the board
/BUS_A10: U3.14 (B6); also elsewhere on the board
/BUS_A11: U3.15 (B5); also elsewhere on the board
/BUS_A12: U3.16 (B4); also elsewhere on the board
/BUS_A13: U3.17 (B3); also elsewhere on the board
/BUS_A14: U3.18 (B2); also elsewhere on the board
/BUS_A15: U3.20 (B1); also elsewhere on the board
/BUS_D0: U2.2 (D0), U5.12 (Q7); also elsewhere on the board
/BUS_D1: U2.3 (D1), U5.13 (Q6); also elsewhere on the board
/BUS_D2: U2.4 (D2), U5.14 (Q5); also elsewhere on the board
/BUS_D3: U2.5 (D3), U5.15 (Q4); also elsewhere on the board
/BUS_D4: U2.6 (D4), U5.16 (Q3); also elsewhere on the board
/BUS_D5: U2.7 (D5), U5.17 (Q2); also elsewhere on the board
/BUS_D6: U2.8 (D6), U5.18 (Q1); also elsewhere on the board
/BUS_D7: U2.9 (D7), U5.19 (Q0); also elsewhere on the board
/BUS_PHI0: U8.12 (B8); also elsewhere on the board
/BUS_R~W: U8.13 (B7), U13.2; also elsewhere on the board
/BUS_~IRQ: U8.14 (B6); also elsewhere on the board
/BUS_~NMI: U8.15 (B5); also elsewhere on the board
/BUS_~RES: U11.4; also elsewhere on the board
/IN_D0: U6.9 (A8); also elsewhere on the board
/IN_D1: U6.8 (A7); also elsewhere on the board
/IN_D2: U6.7 (A6); also elsewhere on the board
/IN_D3: U6.6 (A5); also elsewhere on the board
/IN_D4: U6.5 (A4); also elsewhere on the board
/IN_D5: U6.4 (A3); also elsewhere on the board
/IN_D6: U6.3 (A2); also elsewhere on the board
/IN_D7: U6.1 (A1); also elsewhere on the board
/IN_D_LATCH: U2.11 (Load); also elsewhere on the board
/OUT_A0: U4.9 (A8); also elsewhere on the board
/OUT_A1: U4.8 (A7); also elsewhere on the board
/OUT_A2: U4.7 (A6); also elsewhere on the board
/OUT_A3: U4.6 (A5); also elsewhere on the board
/OUT_A4: U4.5 (A4); also elsewhere on the board
/OUT_A5: U4.4 (A3); also elsewhere on the board
/OUT_A6: U4.3 (A2); also elsewhere on the board
/OUT_A7: U4.1 (A1); also elsewhere on the board
/OUT_A8: U3.9 (A8); also elsewhere on the board
/OUT_A9: U3.8 (A7); also elsewhere on the board
/OUT_A10: U3.7 (A6); also elsewhere on the board
/OUT_A11: U3.6 (A5); also elsewhere on the board
/OUT_A12: U3.5 (A4); also elsewhere on the board
/OUT_A13: U3.4 (A3); also elsewhere on the board
/OUT_A14: U3.3 (A2); also elsewhere on the board
/OUT_A15: U3.1 (A1); also elsewhere on the board
/OUT_D0: U7.9 (A8); also elsewhere on the board
/OUT_D1: U7.8 (A7); also elsewhere on the board
/OUT_D2: U7.7 (A6); also elsewhere on the board
/OUT_D3: U7.6 (A5); also elsewhere on the board
/OUT_D4: U7.5 (A4); also elsewhere on the board
/OUT_D5: U7.4 (A3); also elsewhere on the board
/OUT_D6: U7.3 (A2); also elsewhere on the board
/OUT_D7: U7.1 (A1); also elsewhere on the board
/OUT_D_~PHASE: U13.1; also elsewhere on the board
/OUT_R~W: U8.8 (A7); also elsewhere on the board
/PHI0: U8.9 (A8); also elsewhere on the board
/RES: U8.5 (A4); also elsewhere on the board
/transceivers/IN_5V_D0: U2.19 (Q0), U6.12 (B8)
/transceivers/IN_5V_D1: U2.18 (Q1), U6.13 (B7)
/transceivers/IN_5V_D2: U2.17 (Q2), U6.14 (B6)
/transceivers/IN_5V_D3: U2.16 (Q3), U6.15 (B5)
/transceivers/IN_5V_D4: U2.15 (Q4), U6.16 (B4)
/transceivers/IN_5V_D5: U2.14 (Q5), U6.17 (B3)
/transceivers/IN_5V_D6: U2.13 (Q6), U6.18 (B2)
/transceivers/IN_5V_D7: U2.12 (Q7), U6.20 (B1)
/transceivers/OUT_D_BOARD_~ENABLE: R4.2, U5.1 (OE), U9.4
/transceivers/OUT_D_ENABLE: U9.1, U13.4
/transceivers/OUT_V5_D0: U5.9 (D7), U7.12 (B8)
/transceivers/OUT_V5_D1: U5.8 (D6), U7.13 (B7)
/transceivers/OUT_V5_D2: U5.7 (D5), U7.14 (B6)
/transceivers/OUT_V5_D3: U5.6 (D4), U7.15 (B5)
/transceivers/OUT_V5_D4: U5.5 (D3), U7.16 (B4)
/transceivers/OUT_V5_D5: U5.4 (D2), U7.17 (B3)
/transceivers/OUT_V5_D6: U5.3 (D1), U7.18 (B2)
/transceivers/OUT_V5_D7: U5.2 (D0), U7.20 (B1)
/transceivers/RES_5V: U8.16 (B4), U10.1
/transceivers/~RES_ENABLE: U10.4, U11.2
/~IRQ: U8.7 (A6); also elsewhere on the board
/~NMI: U8.6 (A5); also elsewhere on the board
GND: C5.2, C6.2, C7.2, C8.2, C9.2, C10.2, C11.2, C12.2, C13.2, C14.2, C15.2, C16.2, C17.2, C18.2, C19.2, C20.2, U2.1 (OE), U2.10 (GND), U3.11 (GND), U4.11 (GND), U5.10 (GND), U6.11 (GND), U7.11 (GND), U8.11 (GND), U9.3 (GND), U10.3 (GND), U11.3 (GND), U13.3 (GND); also elsewhere on the board

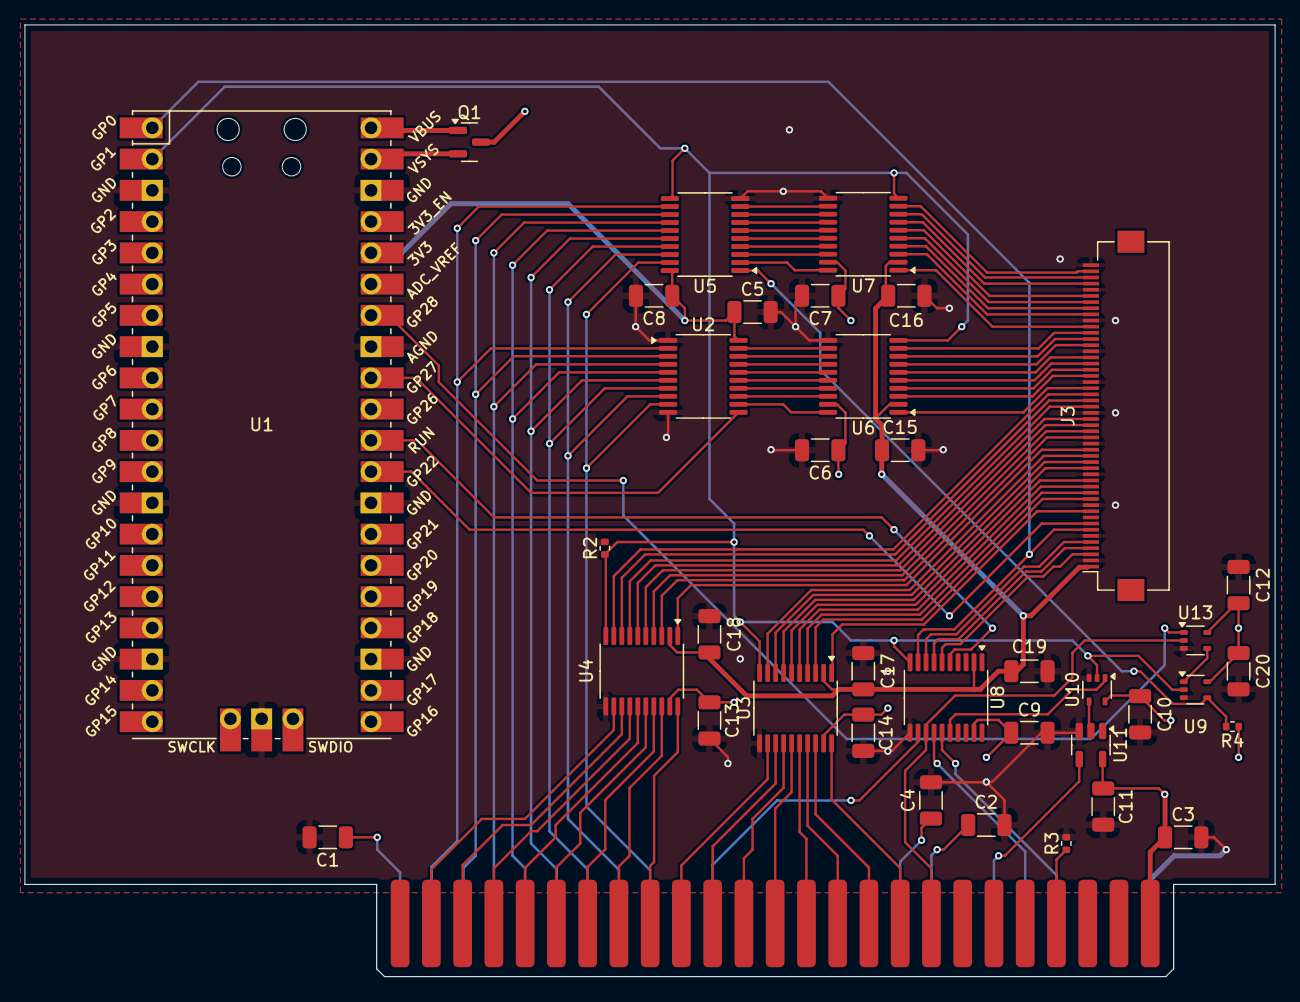
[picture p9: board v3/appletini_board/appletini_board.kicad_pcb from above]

Board: 4 copper layers, 101.6 x 77.3 mm, 38 parts (0 on the bottom side), 100 nets.

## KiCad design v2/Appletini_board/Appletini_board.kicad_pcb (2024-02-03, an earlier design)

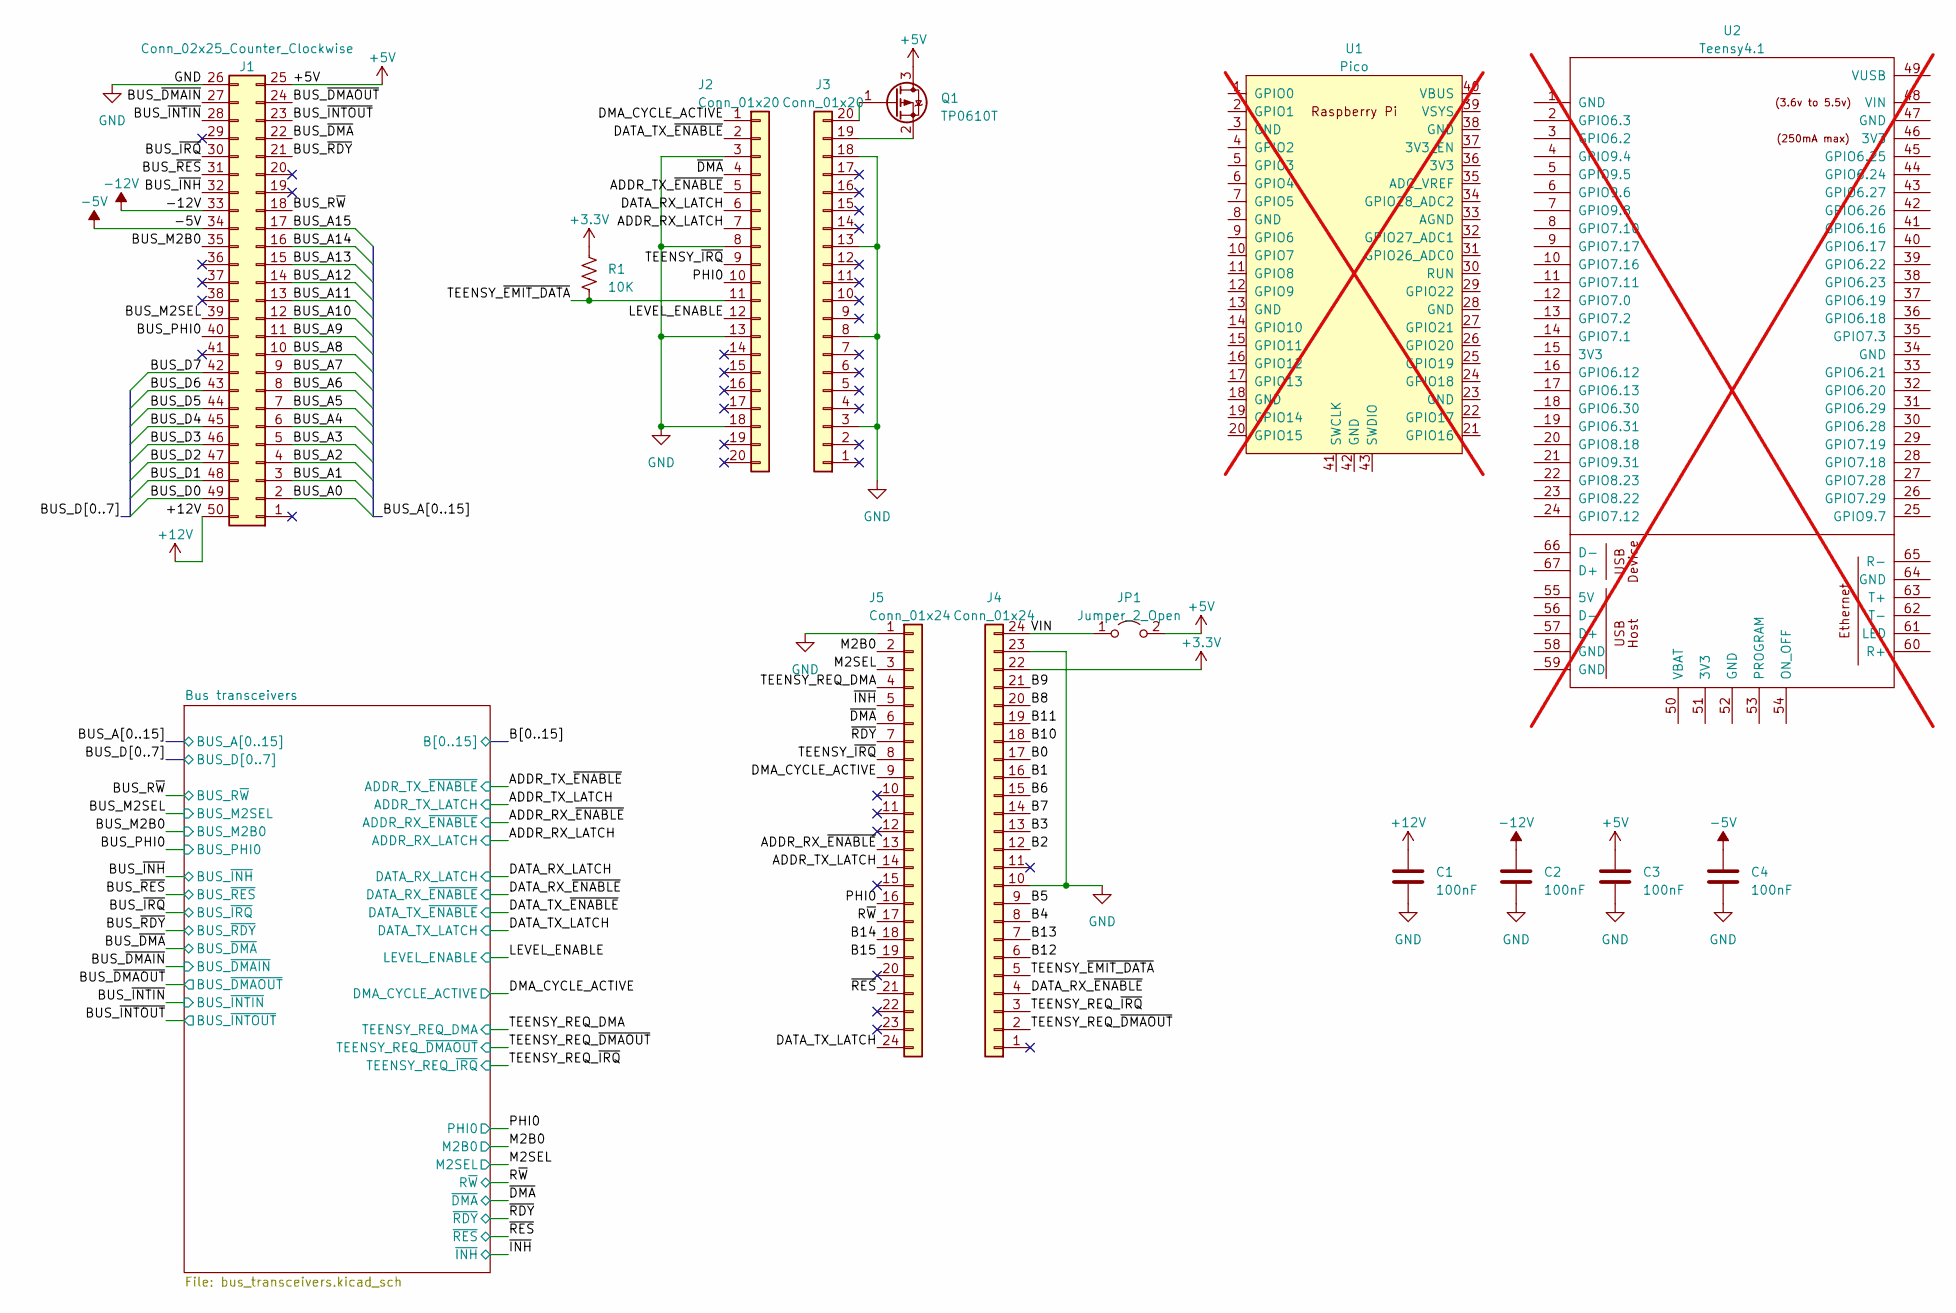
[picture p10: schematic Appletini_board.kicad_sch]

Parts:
C1, C2, C3, C4: 100nF; C_1206_3216Metric; LCSC C24497
J1: Conn_02x25_Counter_Clockwise; AppleIIBus_Edge
J2, J3: Conn_01x20; PinSocket_1x20_P2.54mm_Vertical; LCSC C50984
J4, J5: Conn_01x24; PinSocket_1x24_P2.54mm_Vertical; LCSC C2883741
JP1: Jumper_2_Open; PinHeader_1x02_P2.54mm_Vertical; LCSC C5360898
Q1: TP0610T; SOT-23; LCSC C5261054
R1: 10K; R_0402_1005Metric; LCSC C2991755
U1: Pico; RPi_Pico_SMD_TH; not fitted
U2: Teensy4.1; Teensy41; not fitted

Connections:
+3.3V: J4.22, R1.1; also elsewhere on the board
+5V: C3.1, J1.25, JP1.2 (B), Q1.3 (D); also elsewhere on the board
+12V: C1.1, J1.50
-5V: C4.1, J1.34
-12V: C2.1, J1.33
/ADDR_RX_LATCH: J2.7; also elsewhere on the board
/ADDR_RX_~ENABLE: J5.13; also elsewhere on the board
/ADDR_TX_LATCH: J5.14; also elsewhere on the board
/ADDR_TX_~ENABLE: J2.5; also elsewhere on the board
/B0: J4.17; also elsewhere on the board
/B1: J4.16; also elsewhere on the board
/B2: J4.12; also elsewhere on the board
/B3: J4.13; also elsewhere on the board
/B4: J4.8; also elsewhere on the board
/B5: J4.9; also elsewhere on the board
/B6: J4.15; also elsewhere on the board
/B7: J4.14; also elsewhere on the board
/B8: J4.20; also elsewhere on the board
/B9: J4.21; also elsewhere on the board
/B10: J4.18; also elsewhere on the board
/B11: J4.19; also elsewhere on the board
/B12: J4.6; also elsewhere on the board
/B13: J4.7; also elsewhere on the board
/B14: J5.18; also elsewhere on the board
/B15: J5.19; also elsewhere on the board
/BUS_A0: J1.2; also elsewhere on the board
/BUS_A1: J1.3; also elsewhere on the board
/BUS_A2: J1.4; also elsewhere on the board
/BUS_A3: J1.5; also elsewhere on the board
/BUS_A4: J1.6; also elsewhere on the board
/BUS_A5: J1.7; also elsewhere on the board
/BUS_A6: J1.8; also elsewhere on the board
/BUS_A7: J1.9; also elsewhere on the board
/BUS_A8: J1.10; also elsewhere on the board
/BUS_A9: J1.11; also elsewhere on the board
/BUS_A10: J1.12; also elsewhere on the board
/BUS_A11: J1.13; also elsewhere on the board
/BUS_A12: J1.14; also elsewhere on the board
/BUS_A13: J1.15; also elsewhere on the board
/BUS_A14: J1.16; also elsewhere on the board
/BUS_A15: J1.17; also elsewhere on the board
/BUS_D0: J1.49; also elsewhere on the board
/BUS_D1: J1.48; also elsewhere on the board
/BUS_D2: J1.47; also elsewhere on the board
/BUS_D3: J1.46; also elsewhere on the board
/BUS_D4: J1.45; also elsewhere on the board
/BUS_D5: J1.44; also elsewhere on the board
/BUS_D6: J1.43; also elsewhere on the board
/BUS_D7: J1.42; also elsewhere on the board
/BUS_M2B0: J1.35; also elsewhere on the board
/BUS_M2SEL: J1.39; also elsewhere on the board
/BUS_PHI0: J1.40; also elsewhere on the board
/BUS_R~W: J1.18; also elsewhere on the board
/BUS_~DMAIN: J1.27; also elsewhere on the board
/BUS_~DMAOUT: J1.24; also elsewhere on the board
/BUS_~DMA: J1.22; also elsewhere on the board
/BUS_~INH: J1.32; also elsewhere on the board
/BUS_~INTIN: J1.28; also elsewhere on the board
/BUS_~INTOUT: J1.23; also elsewhere on the board
/BUS_~IRQ: J1.30; also elsewhere on the board
/BUS_~RDY: J1.21; also elsewhere on the board
/BUS_~RES: J1.31; also elsewhere on the board
/DATA_RX_LATCH: J2.6; also elsewhere on the board
/DATA_RX_~ENABLE: J4.4; also elsewhere on the board
/DATA_TX_LATCH: J5.24; also elsewhere on the board
/DATA_TX_~ENABLE: J2.2; also elsewhere on the board
/DMA_CYCLE_ACTIVE: J2.1, J5.9; also elsewhere on the board
/LEVEL_ENABLE: J2.12; also elsewhere on the board
/M2B0: J5.2; also elsewhere on the board
/M2SEL: J5.3; also elsewhere on the board
/PHI0: J2.10, J5.16; also elsewhere on the board
/R~W: J5.17; also elsewhere on the board
/TEENSY_REQ_DMA: J5.4; also elsewhere on the board
/TEENSY_REQ_~DMAOUT: J4.2; also elsewhere on the board
/TEENSY_REQ_~IRQ: J4.3; also elsewhere on the board
/TEENSY_~EMIT_DATA: J2.11, J4.5, R1.2
/TEENSY_~IRQ: J2.9, J5.8
/VIN: J4.24, JP1.1 (A)
/~DMA: J2.4, J5.6; also elsewhere on the board
/~INH: J5.5; also elsewhere on the board
/~RDY: J5.7; also elsewhere on the board
/~RES: J5.21; also elsewhere on the board
GND: C1.2, C2.2, C3.2, C4.2, J1.26, J2.3, J2.8, J2.13, J2.18, J3.3, J3.8, J3.13, J3.18, J4.10, J4.23, J5.1; also elsewhere on the board
unnamed: J3.19, Q1.2 (S)
unnamed: J3.20, Q1.1 (G)

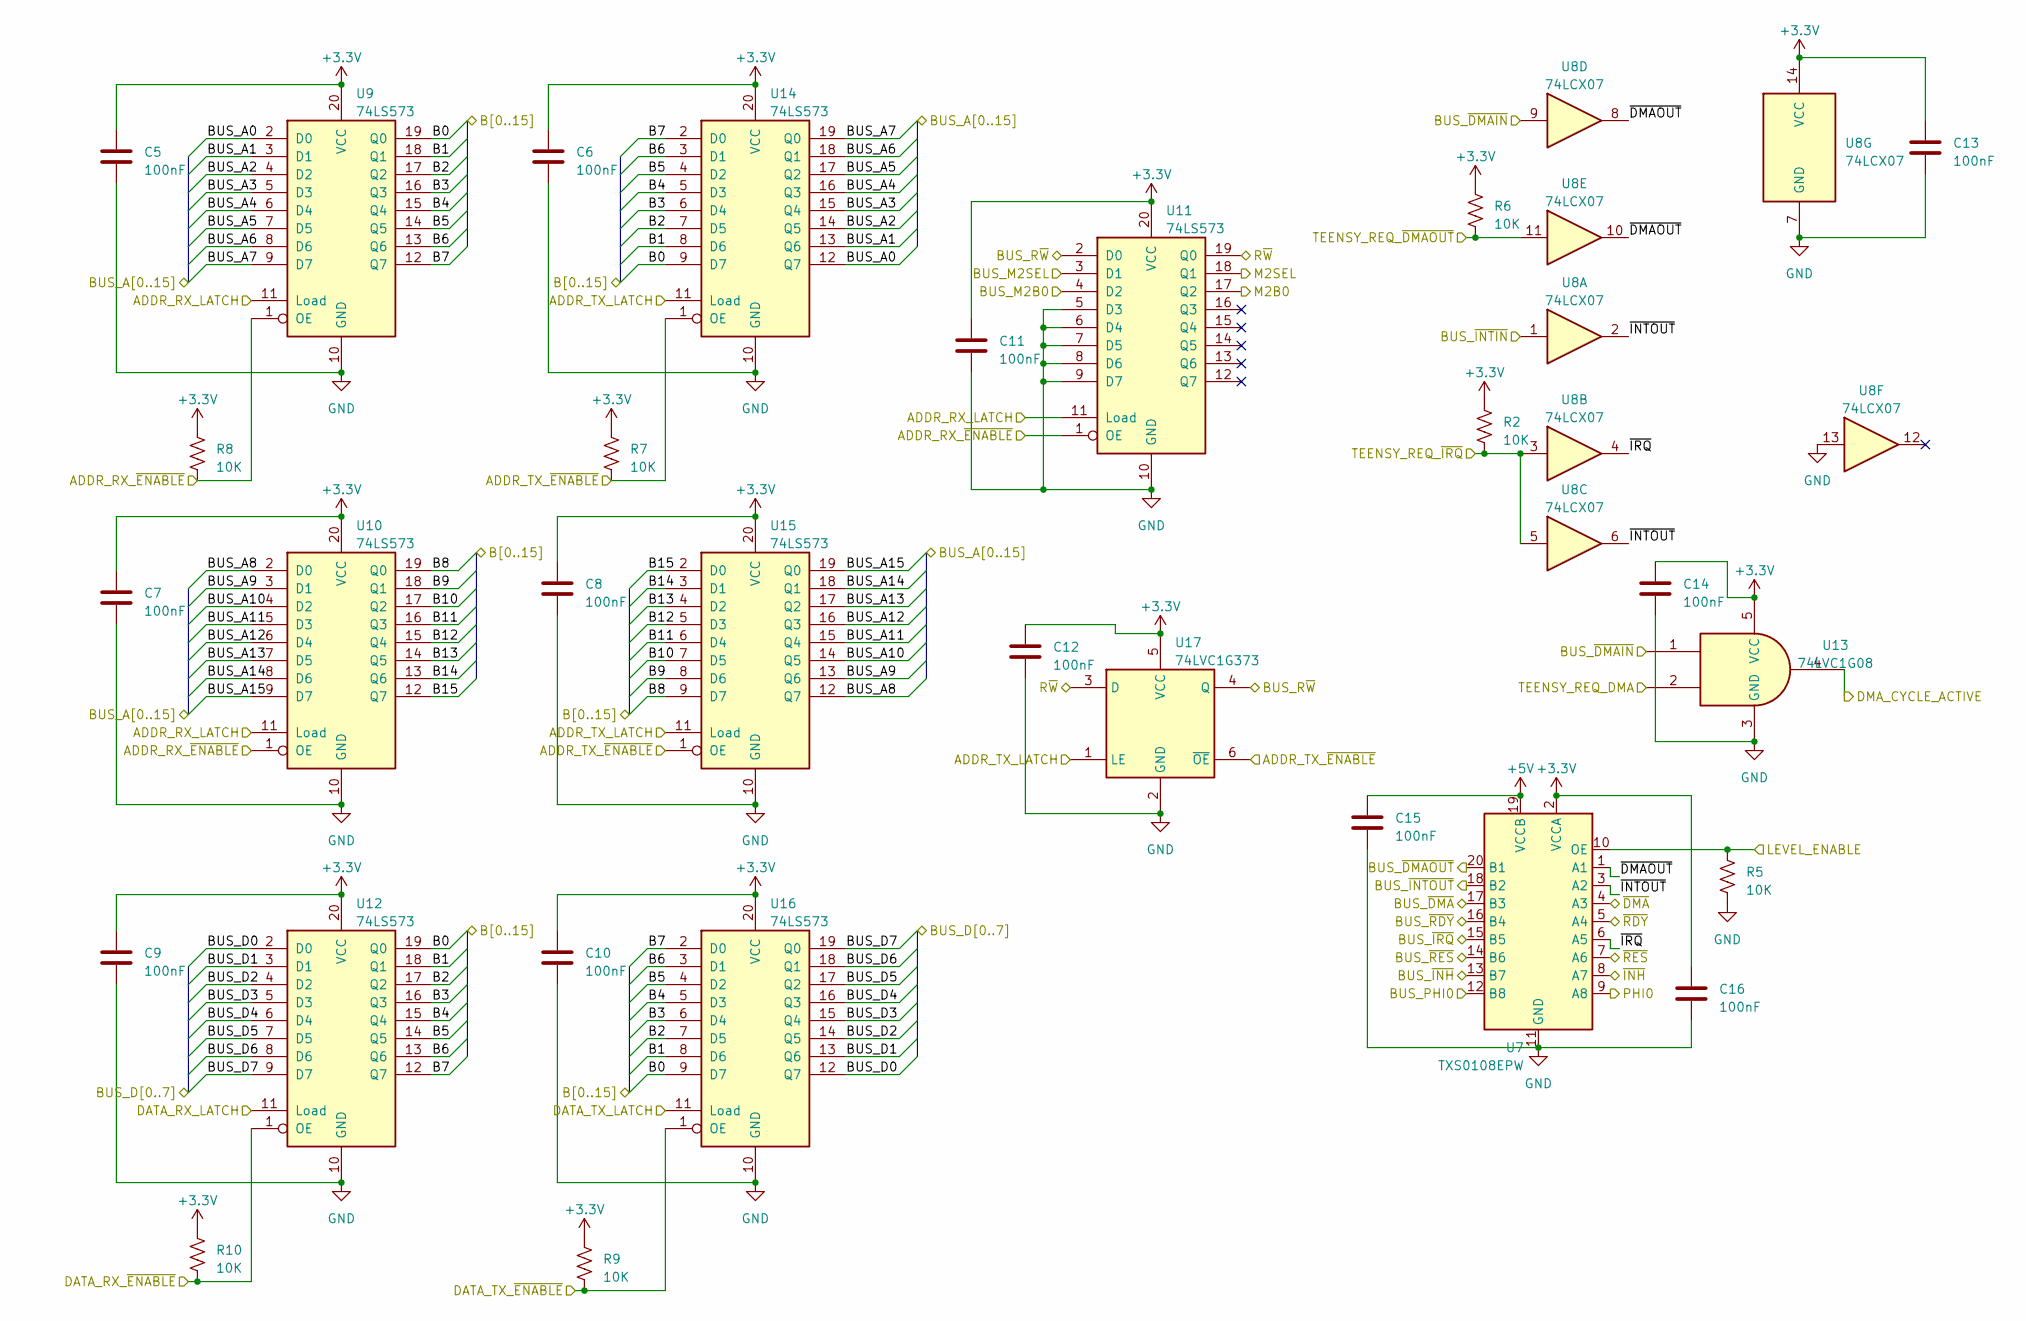
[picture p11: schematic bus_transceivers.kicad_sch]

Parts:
C5, C6, C7, C8, C9, C10, C11, C12: 100nF; C_1206_3216Metric
C13, C14, C15, C16: 100nF; C_1206_3216Metric; LCSC C24497
R2, R6, R7, R8, R9, R10: 10K; R_0402_1005Metric; LCSC C2991755
R5: 10K; R_0402_1005Metric
U7: TXS0108EPW; TSSOP-20_4.4x6.5mm_P0.65mm; LCSC C17206
U8: 74LCX07; TSSOP-14_4.4x5mm_P0.65mm; LCSC C7809
U9: 74LS573; TSSOP-20_4.4x6.5mm_P0.65mm; LCSC C113280
U10, U11, U12, U14, U15, U16: 74LS573; TSSOP-20_4.4x6.5mm_P0.65mm
U13: 74LVC1G08; SOT-23-5; LCSC C7666
U17: 74LVC1G373; SOT-23-6; LCSC C128413

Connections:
+3.3V: C5.1, C6.1, C7.1, C8.1, C9.1, C10.1, C11.1, C12.1, C13.1, C14.1, C16.1, R2.1, R6.1, R7.1, R8.1, R9.1, R10.1, U7.2 (VCCA), U8.14 (VCC), U9.20 (VCC), U10.20 (VCC), U11.20 (VCC), U12.20 (VCC), U13.5 (VCC), U14.20 (VCC), U15.20 (VCC), U16.20 (VCC), U17.5 (VCC); also elsewhere on the board
+5V: C15.1, U7.19 (VCCB); also elsewhere on the board
/ADDR_RX_LATCH: U9.11 (Load), U10.11 (Load), U11.11 (Load); also elsewhere on the board
/ADDR_RX_~ENABLE: R8.2, U9.1 (OE), U10.1 (OE), U11.1 (OE); also elsewhere on the board
/ADDR_TX_LATCH: U14.11 (Load), U15.11 (Load), U17.1 (LE); also elsewhere on the board
/ADDR_TX_~ENABLE: R7.2, U14.1 (OE), U15.1 (OE), U17.6 (~OE); also elsewhere on the board
/B0: U9.19 (Q0), U12.19 (Q0), U14.9 (D7), U16.9 (D7); also elsewhere on the board
/B1: U9.18 (Q1), U12.18 (Q1), U14.8 (D6), U16.8 (D6); also elsewhere on the board
/B2: U9.17 (Q2), U12.17 (Q2), U14.7 (D5), U16.7 (D5); also elsewhere on the board
/B3: U9.16 (Q3), U12.16 (Q3), U14.6 (D4), U16.6 (D4); also elsewhere on the board
/B4: U9.15 (Q4), U12.15 (Q4), U14.5 (D3), U16.5 (D3); also elsewhere on the board
/B5: U9.14 (Q5), U12.14 (Q5), U14.4 (D2), U16.4 (D2); also elsewhere on the board
/B6: U9.13 (Q6), U12.13 (Q6), U14.3 (D1), U16.3 (D1); also elsewhere on the board
/B7: U9.12 (Q7), U12.12 (Q7), U14.2 (D0), U16.2 (D0); also elsewhere on the board
/B8: U10.19 (Q0), U15.9 (D7); also elsewhere on the board
/B9: U10.18 (Q1), U15.8 (D6); also elsewhere on the board
/B10: U10.17 (Q2), U15.7 (D5); also elsewhere on the board
/B11: U10.16 (Q3), U15.6 (D4); also elsewhere on the board
/B12: U10.15 (Q4), U15.5 (D3); also elsewhere on the board
/B13: U10.14 (Q5), U15.4 (D2); also elsewhere on the board
/B14: U10.13 (Q6), U15.3 (D1); also elsewhere on the board
/B15: U10.12 (Q7), U15.2 (D0); also elsewhere on the board
/BUS_A0: U9.2 (D0), U14.12 (Q7); also elsewhere on the board
/BUS_A1: U9.3 (D1), U14.13 (Q6); also elsewhere on the board
/BUS_A2: U9.4 (D2), U14.14 (Q5); also elsewhere on the board
/BUS_A3: U9.5 (D3), U14.15 (Q4); also elsewhere on the board
/BUS_A4: U9.6 (D4), U14.16 (Q3); also elsewhere on the board
/BUS_A5: U9.7 (D5), U14.17 (Q2); also elsewhere on the board
/BUS_A6: U9.8 (D6), U14.18 (Q1); also elsewhere on the board
/BUS_A7: U9.9 (D7), U14.19 (Q0); also elsewhere on the board
/BUS_A8: U10.2 (D0), U15.12 (Q7); also elsewhere on the board
/BUS_A9: U10.3 (D1), U15.13 (Q6); also elsewhere on the board
/BUS_A10: U10.4 (D2), U15.14 (Q5); also elsewhere on the board
/BUS_A11: U10.5 (D3), U15.15 (Q4); also elsewhere on the board
/BUS_A12: U10.6 (D4), U15.16 (Q3); also elsewhere on the board
/BUS_A13: U10.7 (D5), U15.17 (Q2); also elsewhere on the board
/BUS_A14: U10.8 (D6), U15.18 (Q1); also elsewhere on the board
/BUS_A15: U10.9 (D7), U15.19 (Q0); also elsewhere on the board
/BUS_D0: U12.2 (D0), U16.12 (Q7); also elsewhere on the board
/BUS_D1: U12.3 (D1), U16.13 (Q6); also elsewhere on the board
/BUS_D2: U12.4 (D2), U16.14 (Q5); also elsewhere on the board
/BUS_D3: U12.5 (D3), U16.15 (Q4); also elsewhere on the board
/BUS_D4: U12.6 (D4), U16.16 (Q3); also elsewhere on the board
/BUS_D5: U12.7 (D5), U16.17 (Q2); also elsewhere on the board
/BUS_D6: U12.8 (D6), U16.18 (Q1); also elsewhere on the board
/BUS_D7: U12.9 (D7), U16.19 (Q0); also elsewhere on the board
/BUS_M2B0: U11.4 (D2); also elsewhere on the board
/BUS_M2SEL: U11.3 (D1); also elsewhere on the board
/BUS_PHI0: U7.12 (B8); also elsewhere on the board
/BUS_R~W: U11.2 (D0), U17.4 (Q); also elsewhere on the board
/BUS_~DMAIN: U8.9, U13.1; also elsewhere on the board
/BUS_~DMAOUT: U7.20 (B1); also elsewhere on the board
/BUS_~DMA: U7.17 (B3); also elsewhere on the board
/BUS_~INH: U7.13 (B7); also elsewhere on the board
/BUS_~INTIN: U8.1; also elsewhere on the board
/BUS_~INTOUT: U7.18 (B2); also elsewhere on the board
/BUS_~IRQ: U7.15 (B5); also elsewhere on the board
/BUS_~RDY: U7.16 (B4); also elsewhere on the board
/BUS_~RES: U7.14 (B6); also elsewhere on the board
/Bus transceivers/~DMAOUT: U7.1 (A1), U8.8, U8.10
/Bus transceivers/~INTOUT: U7.3 (A2), U8.2, U8.6
/Bus transceivers/~IRQ: U7.6 (A5), U8.4
/DATA_RX_LATCH: U12.11 (Load); also elsewhere on the board
/DATA_RX_~ENABLE: R10.2, U12.1 (OE); also elsewhere on the board
/DATA_TX_LATCH: U16.11 (Load); also elsewhere on the board
/DATA_TX_~ENABLE: R9.2, U16.1 (OE); also elsewhere on the board
/DMA_CYCLE_ACTIVE: U13.4; also elsewhere on the board
/LEVEL_ENABLE: R5.1, U7.10 (OE); also elsewhere on the board
/M2B0: U11.17 (Q2); also elsewhere on the board
/M2SEL: U11.18 (Q1); also elsewhere on the board
/PHI0: U7.9 (A8); also elsewhere on the board
/R~W: U11.19 (Q0), U17.3 (D); also elsewhere on the board
/TEENSY_REQ_DMA: U13.2; also elsewhere on the board
/TEENSY_REQ_~DMAOUT: R6.2, U8.11; also elsewhere on the board
/TEENSY_REQ_~IRQ: R2.2, U8.3, U8.5; also elsewhere on the board
/~DMA: U7.4 (A3); also elsewhere on the board
/~INH: U7.8 (A7); also elsewhere on the board
/~RDY: U7.5 (A4); also elsewhere on the board
/~RES: U7.7 (A6); also elsewhere on the board
GND: C5.2, C6.2, C7.2, C8.2, C9.2, C10.2, C11.2, C12.2, C13.2, C14.2, C15.2, C16.2, R5.2, U7.11 (GND), U8.7 (GND), U8.13, U9.10 (GND), U10.10 (GND), U11.5 (D3), U11.6 (D4), U11.7 (D5), U11.8 (D6), U11.9 (D7), U11.10 (GND), U12.10 (GND), U13.3 (GND), U14.10 (GND), U15.10 (GND), U16.10 (GND), U17.2 (GND); also elsewhere on the board

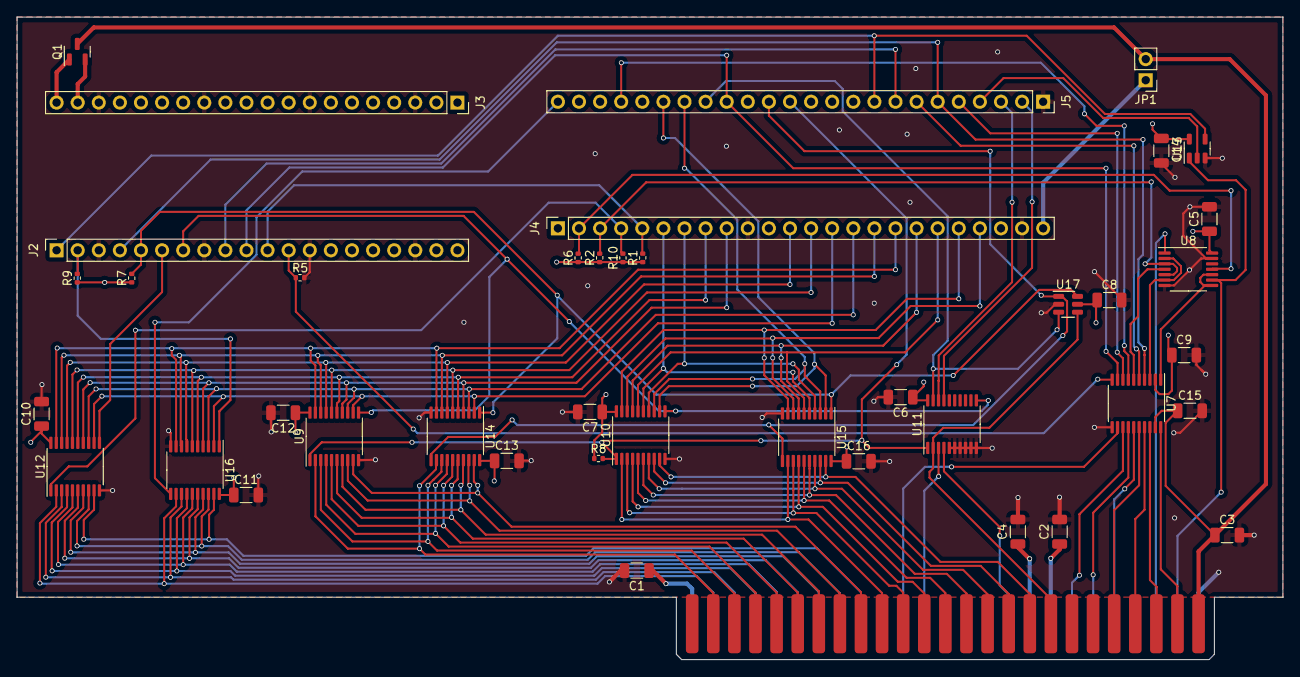
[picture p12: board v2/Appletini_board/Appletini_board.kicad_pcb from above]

Board: 4 copper layers, 152.4 x 77.4 mm, 42 parts (0 on the bottom side), 88 nets.

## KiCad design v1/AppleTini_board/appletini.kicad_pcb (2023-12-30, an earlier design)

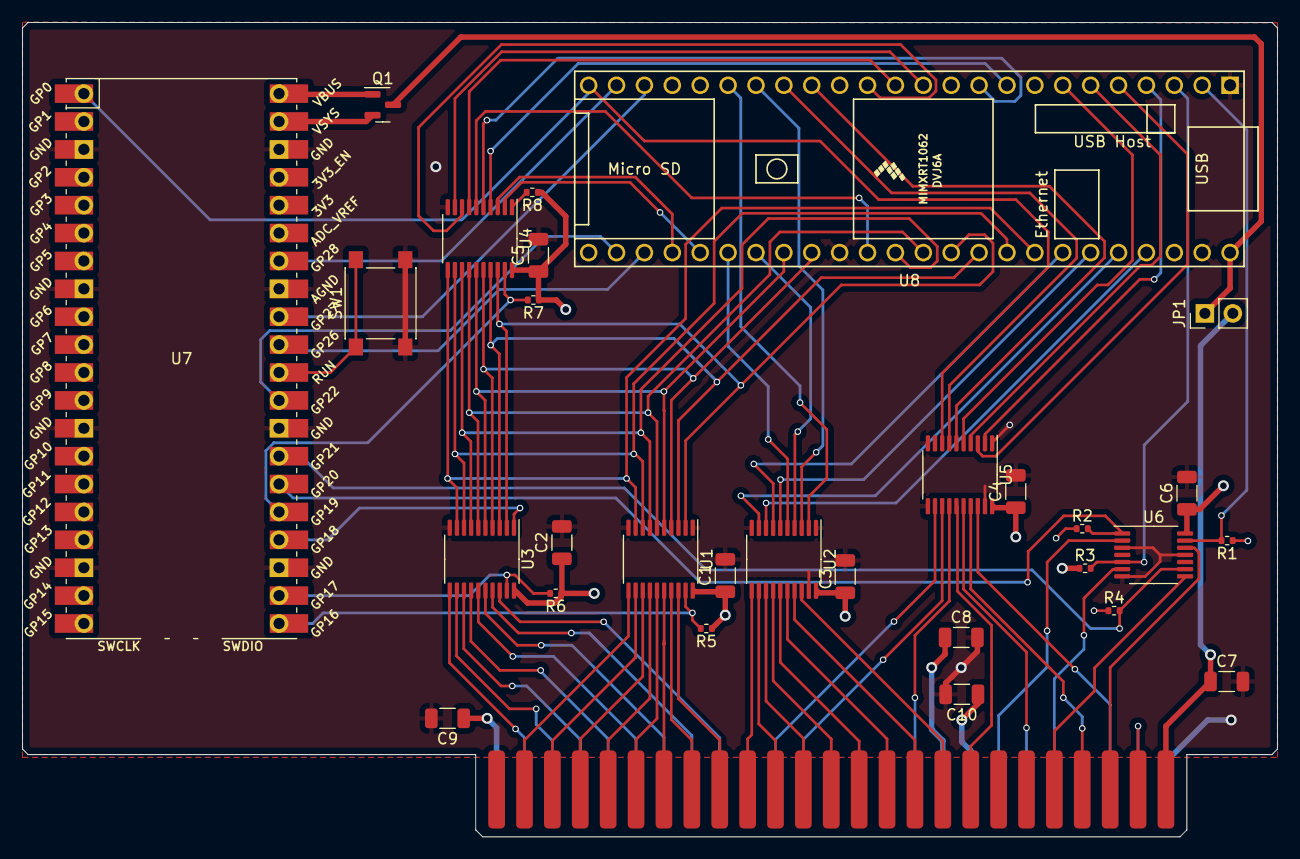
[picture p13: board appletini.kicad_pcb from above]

Board: 4 copper layers, 114.3 x 74.2 mm, 30 parts (0 on the bottom side), 90 nets.

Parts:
C1, C2, C3, C4, C5, C6, C7, C8, C9, C10: 0.1uF; C_1206_3216Metric
J1: Conn_02x25_Counter_Clockwise; AppleIIBus_Edge
JP1: Jumper_2_Open; PinHeader_1x02_P2.54mm_Vertical
Q1: DMG2305UX-7; SOT-23
R1, R2, R3, R4, R5, R6, R7, R8: 10K; R_0402_1005Metric
SW1: SW_Push; SW_Push_1P1T_NO_6x6mm_H9.5mm
U1, U2, U3, U4, U5: 74LS245; TSSOP-20_4.4x6.5mm_P0.65mm
U6: 74LS07; TSSOP-14_4.4x5mm_P0.65mm
U7: Pico; RPi_Pico_SMD_TH
U8: Teensy4.1; Teensy41

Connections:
+3.3V: C1.1, C2.1, C3.1, C4.1, C5.1, C6.1, R1.1, R2.1, R3.1, R4.1, R5.1, R6.1, R7.1, R8.1, U1.20 (VCC), U2.20 (VCC), U3.20 (VCC), U4.20 (VCC), U5.20 (VCC), U6.14 (VCC), U8.46 (3V3)
+5V: C7.1, J1.25, JP1.2 (B)
+12V: C9.1, J1.50
-5V: C8.1, J1.34
-12V: C10.1, J1.33
/ALO_EN: R5.2, U1.19 (CE), U7.21 (GPIO16)
/BUS_A0: J1.2, U1.11 (B7)
/BUS_A1: J1.3, U1.12 (B6)
/BUS_A2: J1.4, U1.13 (B5)
/BUS_A3: J1.5, U1.14 (B4)
/BUS_A4: J1.6, U1.15 (B3)
/BUS_A5: J1.7, U1.16 (B2)
/BUS_A6: J1.8, U1.17 (B1)
/BUS_A7: J1.9, U1.18 (B0)
/BUS_A8: J1.10, U2.11 (B7)
/BUS_A9: J1.11, U2.12 (B6)
/BUS_A10: J1.12, U2.13 (B5)
/BUS_A11: J1.13, U2.14 (B4)
/BUS_A12: J1.14, U2.15 (B3)
/BUS_A13: J1.15, U2.16 (B2)
/BUS_A14: J1.16, U2.17 (B1)
/BUS_A15: J1.17, U2.18 (B0)
/BUS_D0: J1.49, U3.11 (B7)
/BUS_D1: J1.48, U3.12 (B6)
/BUS_D2: J1.47, U3.13 (B5)
/BUS_D3: J1.46, U3.14 (B4)
/BUS_D4: J1.45, U3.15 (B3)
/BUS_D5: J1.44, U3.16 (B2)
/BUS_D6: J1.43, U3.17 (B1)
/BUS_D7: J1.42, U3.18 (B0)
/BUS_DMA: J1.22, U5.17 (B1)
/BUS_DMAPASS: J1.24, J1.27
/BUS_INH: J1.32, U6.2
/BUS_INTIN: J1.28, U5.18 (B0)
/BUS_INTOUT: J1.23, U6.12
/BUS_IRQ: J1.30, U6.6
/BUS_M2B0: J1.35, U5.14 (B4)
/BUS_PHI0: J1.40, U5.12 (B6)
/BUS_RDY: J1.21, U6.8
/BUS_RES: J1.31, U5.16 (B2)
/BUS_RW: J1.18, U5.15 (B3)
/BUS_uSYNC: J1.39, U5.13 (B5)
/DMA: U5.3 (A1), U8.5 (3_LRCLK2)
/D_DIR: U3.1 (A->B), U7.24 (GPIO18)
/D_EN: R6.2, U3.19 (CE), U7.22 (GPIO17)
/INH: R2.2, U6.1, U7.26 (GPIO20)
/INH_REQ: U7.29 (GPIO22), U8.26 (34_RX8)
/INTIN: U5.2 (A0), U8.4 (2_OUT2)
/INTOUT: R1.2, U6.13, U8.2 (0_RX1_CRX2_CS1)
/IRQ: R3.2, U6.5, U8.3 (1_TX1_CTX2_MISO1)
/M2B0: U5.6 (A4), U8.16 (24_A10_TX6_SCL2)
/OUT_D_EN: R7.2, U4.19 (CE), U7.25 (GPIO19)
/OUT_D_REQ: U7.34 (GPIO28_ADC2), U8.23 (31_CTX3)
/PHI0: U5.8 (A6), U7.1 (GPIO0), U8.24 (32_OUT1B)
/RDY: R4.2, U6.9, U7.27 (GPIO21)
/RDY_REQ: U7.31 (GPIO26_ADC0), U8.27 (35_TX8)
/RES: U5.4 (A2), U8.6 (4_BCLK2)
/RW: U5.5 (A3), U8.7 (5_IN2)
/TEENSY_IRQ: U7.32 (GPIO27_ADC1), U8.22 (30_CRX3)
/Transceivers/AHI0: U2.9 (A7), U8.44 (22_A8_CTX1)
/Transceivers/AHI1: U2.8 (A6), U8.45 (23_A9_CRX1_MCLK1)
/Transceivers/AHI2: U2.7 (A5), U8.42 (20_A6_TX5_LRCLK1)
/Transceivers/AHI3: U2.6 (A4), U8.43 (21_A7_RX5_BCLK1)
/Transceivers/AHI4: U2.5 (A3), U8.30 (38_CS1_IN1)
/Transceivers/AHI5: U2.4 (A2), U8.31 (39_MISO1_OUT1A)
/Transceivers/AHI6: U2.3 (A1), U8.18 (26_A12_MOSI1)
/Transceivers/AHI7: U2.2 (A0), U8.19 (27_A13_SCK1)
/Transceivers/ALO_D0: U1.9 (A7), U3.9 (A7), U4.11 (B7), U8.41 (19_A5_SCL)
/Transceivers/ALO_D1: U1.8 (A6), U3.8 (A6), U4.12 (B6), U8.40 (18_A4_SDA)
/Transceivers/ALO_D2: U1.7 (A5), U3.7 (A5), U4.13 (B5), U8.36 (14_A0_TX3_SPDIF_OUT)
/Transceivers/ALO_D3: U1.6 (A4), U3.6 (A4), U4.14 (B4), U8.37 (15_A1_RX3_SPDIF_IN)
/Transceivers/ALO_D4: U1.5 (A3), U3.5 (A3), U4.15 (B3), U8.32 (40_A16)
/Transceivers/ALO_D5: U1.4 (A2), U3.4 (A2), U4.16 (B2), U8.33 (41_A17)
/Transceivers/ALO_D6: U1.3 (A1), U3.3 (A1), U4.17 (B1), U8.39 (17_A3_TX4_SDA1)
/Transceivers/ALO_D7: U1.2 (A0), U3.2 (A0), U4.18 (B0), U8.38 (16_A2_RX4_SCL1)
/Transceivers/OUT_D0: U4.9 (A7), U8.12 (10_CS_MQSR)
/Transceivers/OUT_D1: U4.8 (A6), U8.14 (12_MISO_MQSL)
/Transceivers/OUT_D2: U4.7 (A5), U8.13 (11_MOSI_CTX1)
/Transceivers/OUT_D3: U4.6 (A4), U8.35 (13_SCK_LED)
/Transceivers/OUT_D4: U4.5 (A3), U8.10 (8_TX2_IN1)
/Transceivers/OUT_D5: U4.4 (A2), U8.9 (7_RX2_OUT1A)
/Transceivers/OUT_D6: U4.3 (A1), U8.28 (36_CS)
/Transceivers/OUT_D7: U4.2 (A0), U8.29 (37_CS)
/VBUS: Q1.1 (G), U7.40 (VBUS)
/VIN: JP1.1 (A), Q1.3 (D), U8.48 (VIN)
/VSYS: Q1.2 (S), U7.39 (VSYS)
/uSYNC: U5.7 (A5), U8.17 (25_A11_RX6_SDA2)
GND: C1.2, C2.2, C3.2, C4.2, C5.2, C6.2, C7.2, C8.2, C9.2, C10.2, J1.26, SW1.2, U1.1 (A->B), U1.10 (GND), U2.1 (A->B), U2.10 (GND), U2.19 (CE), U3.10 (GND), U4.10 (GND), U5.1 (A->B), U5.10 (GND), U5.11 (B7), U5.19 (CE), U6.3, U6.7 (GND), U6.11, U7.3 (GND), U7.8 (GND), U7.13 (GND), U7.18 (GND), U7.23 (GND), U7.28 (GND), U7.33 (AGND), U7.38 (GND), U8.1 (GND), U8.34 (GND), U8.47 (GND)
unnamed: R8.2, U4.1 (A->B)
unnamed: SW1.1, U7.30 (RUN)

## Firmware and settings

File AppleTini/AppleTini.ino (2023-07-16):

/*
 AppleTini:
 This installs an ISR which watches for two control pins: AddressReady and
 DataReady, waiting for a negative edge transition on each.

 When AddressReady signals, the ISR reads the 16 bits of Apple bus address,
 and the RW bit, and saves them for the DataReady phase.  In addition, if
 the RW flag indicates a read, it examines the address and decides whether
 to emit the byte read, or not.  It sets the active-low DataOutput pin
 appropriately, and puts the emitted byte onto the 8 data-out pins.

 When DataReady signals, the ISR reads the 8 bits of Apple bus data (which
 if we emitted a byte on the previous AddressReady phase, will be the same
 byte we wrote out), and pushes the entire 25 bit bus event (16 address, RW,
 8 data) to a ring buffer for the main loop to pick up and write out over
 UDP.

 */

#include <QNEthernet.h>


// Enter a MAC address and IP address for your controller below.
// The IP address will be dependent on your local network:
// byte mac[] = {
//   0xDE, 0xAD, 0xBE, 0xEF, 0xFE, 0xED
// };
IPAddress ipaddr(192, 168, 1, 177);
IPAddress netmask(255, 255, 255, 0);
IPAddress gw(192, 168, 1, 1);
IPAddress host(192, 168, 1, 107);

namespace qn = qindesign::network;

unsigned int localPort = 8080;  // local port to listen on

// buffers for receiving and sending data
uint8_t packetBuffer[1500];  // buffer to hold incoming packet,
//char ReplyBuffer[] = "acknowledged";        // a string to send back

// An EthernetUDP instance to let us send and receive packets over UDP
qn::EthernetUDP Udp;

uint32_t last_micros = 0;
uint8_t tx_buf[2048];
uint8_t* p = tx_buf;
uint16_t prev_tx_address = 0;
uint32_t next_tx_seqno = 0;
uint16_t bus_address = 0;
uint8_t bus_user1 = true;
uint8_t bus_rw = true;
bool io_strobe = false;
uint8_t iosel_memory[256];
uint8_t rom_strobe_memory[2048];
uint32_t event_ring[256];
uint8_t event_ring_begin = 0;
volatile uint8_t event_ring_end = 0;
uint8_t slotc3rom = 0;
uint8_t intcxrom = 0;
uint8_t appletini_dev_enabled = 0;
volatile bool reset_occurred = false;
bool reset_pin = true;
uint8_t result_buf[256];
uint8_t result_len = 0;
uint8_t* result_ptr = result_buf;

struct time_struct {
  int32_t epoch_sec;
  int32_t millis;
} last_timestamp;

uint32_t last_timestamp_reference = 0;

#define APPLETINI_SLOT 2

#define DEVSEL_RANGE (0xc080 + (APPLETINI_SLOT << 4))
#define DEVSEL_MASK 0xfff0
#define IOSEL_RANGE (0xc000 + (APPLETINI_SLOT << 8))
#define IOSEL_MASK 0xff00
#define STROBE_RANGE 0xc800
#define STROBE_MASK 0xf800

#define CLRINTCXROM 0xc006
#define SETINTCXROM 0xc007
#define CLRSLOTC3ROM 0xc00a
#define SETSLOTC3ROM 0xc00b
#define RDCXROM 0xc015
#define RDC3ROM 0xc017

// data bits are scattered on GPIO7 register.
// the two clumps of 4 at 0-3 and 16-19 are the
// low and high half of the data byte, the remaining bit
// is the data_out_control pin
#define DATA_OUT_MASK 0x000f040f

FASTRUN static inline void check_soft_switches(uint8_t data) {
  if ((bus_address & 0xf000) == 0xc000) {
    if (bus_rw) {
      // read switches of interest
      if (appletini_dev_enabled && (bus_address & IOSEL_MASK) == IOSEL_RANGE) {
        io_strobe = true;
      } else if (bus_address == 0xcfff) {
        io_strobe = false;
      } else if (bus_address == RDCXROM) {
        intcxrom = (data & 0x80) != 0;
#if APPLETINI_SLOT == 3
      } else if (bus_address == RDC3ROM) {
        slotc3rom = (data & 0x80) != 0;
        appletini_dev_enabled = !slotc3rom || !intcxrom;
#else
        appletini_dev_enabled = !intcxrom;
#endif
      }
    } else {
      if ((bus_address & DEVSEL_MASK) == DEVSEL_RANGE) {
        handle_devsel_address_write(bus_address, data);
      }
      if (bus_address == CLRINTCXROM) {
        //Serial.println("CLRINTCXROM");
        intcxrom = false;
      }
      if (bus_address == SETINTCXROM) {
        //Serial.println("SETINTCXROM");
        intcxrom = true;
      }
#if APPLETINI_SLOT == 3
      if (bus_address == CLRSLOTC3ROM) {
        //Serial.println("CLRSLOTC3ROM");
        slotc3rom = false;
      }
      if (bus_address == SETSLOTC3ROM) {
        //Serial.println("SETSLOTC3ROM");
        slotc3rom = true;
      }
      appletini_dev_enabled = !slotc3rom || !intcxrom;
#else
      appletini_dev_enabled = !intcxrom;
#endif
      //Serial.print("appletini_dev_enabled:");
      //Serial.println(appletini_dev_enabled);
    }
  }
}

FASTRUN static inline void handle_reset() {
  // Serial.println("Reset occurred");
  intcxrom = false;
  slotc3rom = false;
  if (p != tx_buf) {
    // write out the current packet in progress immediately
    Udp.beginPacket(host, localPort);
    Udp.write(tx_buf, p - tx_buf);
    Udp.endPacket();
    p = tx_buf;
  }
  *p++ = next_tx_seqno & 0xff;
  *p++ = (next_tx_seqno >> 8) & 0xff;
  *p++ = (next_tx_seqno >> 16) & 0xff;
  *p++ = (next_tx_seqno >> 24) & 0xff;
  *p++ = 2;  // reset is message type 2
  Udp.beginPacket(host, localPort);
  Udp.write(tx_buf, p - tx_buf);
  Udp.endPacket();
  p = tx_buf;
}

FASTRUN static inline uint8_t handle_devsel_address_read(uint16_t address) {
  //Serial.print("handledevsel:");
  //Serial.println(address);
  uint8_t val = address & 0x0f;
  switch (val) {
    // currently only handle result address read in byte 3
    case 3: break;
    default: return val;
  }
  if (result_ptr == result_buf + result_len) {
    return 0;
  }
  val = *result_ptr++;
  return val;
}

FASTRUN static inline void handle_card_command(uint8_t val) {
  //Serial.print("card command:");
  //Serial.print(val);
  switch (val) {
    case 0:
      {
        //Serial.println("sending time");
        uint32_t now = millis();
        int32_t adj = now - last_timestamp_reference;
        last_timestamp_reference = now;
        int32_t adj_millis = last_timestamp.millis + adj;
        // compiler might be smart enough to optimize this
        // automatically but being explicit using div()
        ldiv_t ret = ldiv(adj_millis, (int32_t)1000);
        last_timestamp.epoch_sec += ret.quot;
        last_timestamp.millis = ret.rem;
        result_ptr = result_buf;
        result_len = 7;
        result_buf[0] = result_len;
        result_buf[1] = last_timestamp.epoch_sec & 0xff;
        result_buf[2] = (last_timestamp.epoch_sec >> 8) & 0xff;
        result_buf[3] = (last_timestamp.epoch_sec >> 16) & 0xff;
        result_buf[4] = (last_timestamp.epoch_sec >> 24) & 0xff;
        result_buf[5] = last_timestamp.millis & 0xff;
        result_buf[6] = (last_timestamp.millis >> 8) & 0xff;
      }
      break;
    default: break;
  }
}

FASTRUN static inline void handle_devsel_address_write(uint16_t address, uint8_t val) {
  uint8_t addr_val = address & 0x0f;
  switch (addr_val) {
    // currently only handle writes to card command address in byte 2
    case 2: handle_card_command(val); break;
    default: break;
  }
}

FASTRUN static inline void do_address_phase(uint32_t pins) {
  // first disable data_out_control pin (set high, as it is active-low)
  GPIO7_DR_SET = CORE_PIN6_BITMASK;

  // we arranged for the address pins to be the contiguous set of bits 16-31
  bus_address = (pins >> 16) & 0xffff;
  // toggle io_strobe if needed
  bus_rw = (pins >> 13) & 0x01;
  bus_user1 = (pins >> 12) & 0x01;
  // check if this is a read that we will service
  if (bus_rw && ((bus_address & DEVSEL_MASK) == DEVSEL_RANGE)) {
    uint8_t data_byte = handle_devsel_address_read(bus_address);
    //Serial.print("emit:");
    //Serial.print(bus_address);
    //Serial.print(":");
    //Serial.println(data_byte);
    uint32_t data_register = ((uint32_t)data_byte & 0xf0) << 12;
    data_register |= data_byte & 0x0f;
    GPIO7_DR_CLEAR = DATA_OUT_MASK;
    GPIO7_DR_SET = data_register;
  } else if (appletini_dev_enabled && bus_rw) {
    uint8_t data_byte;
    bool emit = true;
    if ((bus_address & IOSEL_MASK) == IOSEL_RANGE) {
      data_byte = iosel_memory[bus_address & 0x00ff];
    } else if (io_strobe && ((bus_address & STROBE_MASK) == STROBE_RANGE)) {
      data_byte = rom_strobe_memory[bus_address & 0x7ff];
    } else {
      emit = false;
    }
    if (emit) {
      //Serial.print("emit:");
      //Serial.print(bus_address);
      //Serial.print(":");
      //Serial.println(data_byte);
      uint32_t data_register = ((uint32_t)data_byte & 0xf0) << 12;
      data_register |= data_byte & 0x0f;
      GPIO7_DR_CLEAR = DATA_OUT_MASK;
      GPIO7_DR_SET = data_register;
    }
  }
}


FASTRUN static inline void do_data_phase(uint32_t pins) {
  // reset pin on GPIO7, and handling reset not time critical so do in data phase
  uint32_t port7_pins = GPIO7_PSR;
  bool new_reset_pin = (port7_pins >> 11) & 0x01;
  if (new_reset_pin != reset_pin) {
    reset_pin = new_reset_pin;
    if (reset_pin == 0) {
      reset_occurred = true;
    }
  }
  uint8_t data = (pins >> 24) & 0xff;
  check_soft_switches(data);

  uint32_t event = data;
  event |= (uint32_t)bus_address << 8;
  if (bus_rw) {
    event |= 1 << 24;
  }
  event_ring[event_ring_end++] = event;
}

#define IMR_INDEX 5
#define ISR_INDEX 6

FASTRUN void bus_handler() {
  // snap the pins immediately
  uint32_t port6_pins = GPIO6_PSR;
  // clear interrupts.  We are doing it slightly faster than the
  // stock interrupt code, because we know we are the only gpio
  // interrupt running, and we are only on GPIO6.
  volatile uint32_t* drp = &GPIO6_DR;
  uint32_t interrupt_status = drp[ISR_INDEX] & drp[IMR_INDEX];
  drp[ISR_INDEX] = interrupt_status;  // this clears the interrupt

  if (port6_pins & CORE_PIN1_BITMASK) {
    do_data_phase(port6_pins);
  } else {
    do_address_phase(port6_pins);
  }
  asm("dsb");  // memory barrier to flush everything
}


void setup() {
  // You can use Ethernet.init(pin) to configure the CS pin
  //Ethernet.init(10);  // Most Arduino shields
  //Ethernet.init(5);   // MKR ETH shield
  //Ethernet.init(0);   // Teensy 2.0
  //Ethernet.init(20);  // Teensy++ 2.0
  //Ethernet.init(15);  // ESP8266 with Adafruit Featherwing Ethernet
  //Ethernet.init(33);  // ESP32 with Adafruit Featherwing Ethernet

  // set pin directions
  // disable all pins
  for (int i = 0; i < 42; ++i) {
    pinMode(i, INPUT_DISABLE);
  }

  // GPIO6 pins start here
  // addr0-16, numbers are wacky because the pin->register bit
  // mapping is totally wacky
  pinMode(19, INPUT);
  pinMode(18, INPUT);
  pinMode(14, INPUT);
  pinMode(15, INPUT);
  pinMode(40, INPUT);
  pinMode(41, INPUT);
  pinMode(17, INPUT);
  pinMode(16, INPUT);
  pinMode(22, INPUT);
  pinMode(23, INPUT);
  pinMode(20, INPUT);
  pinMode(21, INPUT);
  pinMode(38, INPUT);
  pinMode(39, INPUT);
  pinMode(26, INPUT);
  pinMode(27, INPUT);
  // user1
  pinMode(24, INPUT);
  // rw pin
  pinMode(25, INPUT);
  // PHI0
  pinMode(1, INPUT);
  // interrupt
  pinMode(0, INPUT);
  // GPIO7 ports start here
  // data_out_control
  pinMode(6, OUTPUT);
  // RESET
  pinMode(9, INPUT);  // note, input, as we ran out of GPIO6 inputs
  // data_out0-8
  pinMode(10, OUTPUT);
  pinMode(12, OUTPUT);
  pinMode(11, OUTPUT);
  pinMode(13, OUTPUT);
  pinMode(8, OUTPUT);
  pinMode(7, OUTPUT);
  pinMode(36, OUTPUT);
  pinMode(37, OUTPUT);

  // let the lib code in attachInterrupt do its config details
  attachInterrupt(digitalPinToInterrupt(0), bus_handler, FALLING);

  // override the vector for gpio directly to our handler to
  // skip dispatching
  attachInterruptVector(IRQ_GPIO6789, &bus_handler);

  // start the Ethernet
  qn::Ethernet.begin(ipaddr, netmask, gw);

  // Open serial communications and wait for port to open:
  // Serial.begin(9600);
  // while (!Serial) {
  //   ;  // wait for serial port to connect. Needed for native USB port only
  // }

  // Serial.println("starting udp");
  // // start UDP
  Udp.begin(localPort);
  // Serial.println("started udp");

  // set GPIO priority to highest priority, as
  // handling the bus is hard-realtime
  for (int i = 0; i < NVIC_NUM_INTERRUPTS; ++i) {
    uint32_t prio = NVIC_GET_PRIORITY(i);
    if (prio < 16) {
      // Serial.print("interrupt prio 0:");
      // Serial.println(i);
      NVIC_SET_PRIORITY(i, 16);
    }
    NVIC_SET_PRIORITY(IRQ_GPIO6789, 0);
  }
}

void handle_echo(uint8_t* buf, int size) {
  memcpy(p, buf, size);
  p += size;
}

void handle_timestamp(uint8_t* buf, int size) {
  last_timestamp_reference = millis();
  memcpy((void*)&last_timestamp, (void*)buf, sizeof(last_timestamp));
  // Serial.print(last_timestamp.epoch_sec);
  // Serial.print(".");
  // Serial.println(last_timestamp.millis);
}

void handle_rx_packet(uint8_t* buf, int size) {
  if (p != tx_buf) {
    // write out the current packet in progress immediately
    Udp.beginPacket(host, localPort);
    Udp.write(tx_buf, p - tx_buf);
    Udp.endPacket();
    p = tx_buf;
  }
  ++next_tx_seqno;
  *p++ = next_tx_seqno & 0xff;
  *p++ = (next_tx_seqno >> 8) & 0xff;
  *p++ = (next_tx_seqno >> 16) & 0xff;
  *p++ = (next_tx_seqno >> 24) & 0xff;
  // get the msg type and echo back the rx seqno
  uint8_t msg_type = buf[4];
  *p++ = msg_type;
  *p++ = buf[0];
  *p++ = buf[1];
  *p++ = buf[2];
  *p++ = buf[3];
  buf += 5;
  switch (msg_type) {
    case 1:
      handle_echo(buf, size - 5);
      break;
    case 2:
      // reset message, should never be getting it
      break;
    case 3:
      // timestamp message
      handle_timestamp(buf, size - 5);
    default:
      break;
  }
  Udp.beginPacket(host, localPort);
  Udp.write(tx_buf, p - tx_buf);
  Udp.endPacket();
  p = tx_buf;
}

void loop() {
  // if a reset occurred, process it
  if (reset_occurred) {
    reset_occurred = false;
    handle_reset();
  }
  // if there's data available, read a packet
  int packetSize = Udp.parsePacket();
  if (packetSize >= 0) {
    // read the packet into packetBufffer
    Udp.read(packetBuffer, packetSize);
    handle_rx_packet(packetBuffer, packetSize);
  }
  // make safe nonvolatile copy of event_ring_end for processing
  //cli();
  uint32_t ring_end = event_ring_end;
  //sei();
  uint32_t buffered_events;
  if (ring_end < event_ring_begin) {
    buffered_events = 256 + ring_end - event_ring_begin;
  } else {
    buffered_events = ring_end - event_ring_begin;
  }
  while (buffered_events >= 8) {
    buffered_events -= 8;
    if (p == tx_buf) {
      ++next_tx_seqno;
      *p++ = next_tx_seqno & 0xff;
      *p++ = (next_tx_seqno >> 8) & 0xff;
      *p++ = (next_tx_seqno >> 16) & 0xff;
      *p++ = (next_tx_seqno >> 24) & 0xff;
      *p++ = 0;
    }
    uint8_t* rw_flags = p++;
    uint8_t* seq_flags = p++;
    uint8_t* data_p = p;
    *rw_flags = 0;
    *seq_flags = 0;
    p += 8;
    for (int i = 0; i < 8; ++i) {
      uint32_t event = event_ring[event_ring_begin++];
      //Serial.println(event, HEX);
      if (event & (1 << 24)) {
        *rw_flags |= 1 << i;
      }
      uint8_t data = event & 0xff;
      data_p[i] = data;
      uint16_t address = (event >> 8) & 0xffff;
      if (address != prev_tx_address + 1) {
        *seq_flags |= 1 << i;
        uint8_t addrlo = address & 0xff;
        *p++ = addrlo;
        uint8_t addrhi = (address >> 8) & 0xff;
        *p++ = addrhi;
      }
      prev_tx_address = address;
    }
    if (p - tx_buf >= 256) {
      Udp.beginPacket(host, localPort);
      Udp.write(tx_buf, p - tx_buf);
      Udp.endPacket();
      p = tx_buf;
    }
  }
}

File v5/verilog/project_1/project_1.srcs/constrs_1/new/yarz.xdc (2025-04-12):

# set_property PACKAGE_PIN D17 [get_ports "clk_p"] 
# set_property IOSTANDARD LVDS [get_ports "clk_p"] 
# #
# set_property PACKAGE_PIN C17 [get_ports "clk_n"] 
# set_property IOSTANDARD LVDS [get_ports "clk_n"]

# ft_clk => 100000000Hz
create_clock -period 10.0 -name ft_clk_0 -waveform {0.000 5.000} [get_ports ft_clk]
set_property PACKAGE_PIN V4 [get_ports {ft_clk}]
set_property IOSTANDARD LVCMOS18 [get_ports {ft_clk}]
set_property PACKAGE_PIN W6 [get_ports {ft_rxf}]
set_property IOSTANDARD LVCMOS18 [get_ports {ft_rxf}]
set_property PACKAGE_PIN W5 [get_ports {ft_txe}]
set_property IOSTANDARD LVCMOS18 [get_ports {ft_txe}]

set_property PACKAGE_PIN R3 [get_ports {ft_data[0]}]
set_property IOSTANDARD LVCMOS18 [get_ports {ft_data[0]}]
set_property PACKAGE_PIN R2 [get_ports {ft_data[1]}]
set_property IOSTANDARD LVCMOS18 [get_ports {ft_data[1]}]
set_property PACKAGE_PIN T1 [get_ports {ft_data[2]}]
set_property IOSTANDARD LVCMOS18 [get_ports {ft_data[2]}]
set_property PACKAGE_PIN U2 [get_ports {ft_data[3]}]
set_property IOSTANDARD LVCMOS18 [get_ports {ft_data[3]}]
set_property PACKAGE_PIN U1 [get_ports {ft_data[4]}]
set_property IOSTANDARD LVCMOS18 [get_ports {ft_data[4]}]
set_property PACKAGE_PIN V2 [get_ports {ft_data[5]}]
set_property IOSTANDARD LVCMOS18 [get_ports {ft_data[5]}]
set_property PACKAGE_PIN W2 [get_ports {ft_data[6]}]
set_property IOSTANDARD LVCMOS18 [get_ports {ft_data[6]}]
set_property PACKAGE_PIN W1 [get_ports {ft_data[7]}]
set_property IOSTANDARD LVCMOS18 [get_ports {ft_data[7]}]
set_property PACKAGE_PIN Y2 [get_ports {ft_data[8]}]
set_property IOSTANDARD LVCMOS18 [get_ports {ft_data[8]}]
set_property PACKAGE_PIN Y1 [get_ports {ft_data[9]}]
set_property IOSTANDARD LVCMOS18 [get_ports {ft_data[9]}]
set_property PACKAGE_PIN U3 [get_ports {ft_data[10]}]
set_property IOSTANDARD LVCMOS18 [get_ports {ft_data[10]}]
set_property PACKAGE_PIN V3 [get_ports {ft_data[11]}]
set_property IOSTANDARD LVCMOS18 [get_ports {ft_data[11]}]
set_property PACKAGE_PIN AB3 [get_ports {ft_data[12]}]
set_property IOSTANDARD LVCMOS18 [get_ports {ft_data[12]}]
set_property PACKAGE_PIN AB2 [get_ports {ft_data[13]}]
set_property IOSTANDARD LVCMOS18 [get_ports {ft_data[13]}]
set_property PACKAGE_PIN AB1 [get_ports {ft_data[14]}]
set_property IOSTANDARD LVCMOS18 [get_ports {ft_data[14]}]
set_property PACKAGE_PIN AA1 [get_ports {ft_data[15]}]
set_property IOSTANDARD LVCMOS18 [get_ports {ft_data[15]}]

set_property PACKAGE_PIN AB8 [get_ports {ft_data[16]}]
set_property IOSTANDARD LVCMOS18 [get_ports {ft_data[16]}]
set_property PACKAGE_PIN AA8 [get_ports {ft_data[17]}]
set_property IOSTANDARD LVCMOS18 [get_ports {ft_data[17]}]
set_property PACKAGE_PIN V9 [get_ports {ft_data[18]}]
set_property IOSTANDARD LVCMOS18 [get_ports {ft_data[18]}]
set_property PACKAGE_PIN AB7 [get_ports {ft_data[19]}]
set_property IOSTANDARD LVCMOS18 [get_ports {ft_data[19]}]
set_property PACKAGE_PIN AB6 [get_ports {ft_data[20]}]
set_property IOSTANDARD LVCMOS18 [get_ports {ft_data[20]}]
set_property PACKAGE_PIN Y3 [get_ports {ft_data[21]}]
set_property IOSTANDARD LVCMOS18 [get_ports {ft_data[21]}]
set_property PACKAGE_PIN AA4 [get_ports {ft_data[22]}]
set_property IOSTANDARD LVCMOS18 [get_ports {ft_data[22]}]
set_property PACKAGE_PIN AA5 [get_ports {ft_data[23]}]
set_property IOSTANDARD LVCMOS18 [get_ports {ft_data[23]}]
set_property PACKAGE_PIN AB5 [get_ports {ft_data[24]}]
set_property IOSTANDARD LVCMOS18 [get_ports {ft_data[24]}]
set_property PACKAGE_PIN AA3 [get_ports {ft_data[25]}]
set_property IOSTANDARD LVCMOS18 [get_ports {ft_data[25]}]
set_property PACKAGE_PIN Y4 [get_ports {ft_data[26]}]
set_property IOSTANDARD LVCMOS18 [get_ports {ft_data[26]}]
set_property PACKAGE_PIN Y7 [get_ports {ft_data[27]}]
set_property IOSTANDARD LVCMOS18 [get_ports {ft_data[27]}]
set_property PACKAGE_PIN Y8 [get_ports {ft_data[28]}]
set_property IOSTANDARD LVCMOS18 [get_ports {ft_data[28]}]
set_property PACKAGE_PIN W7 [get_ports {ft_data[29]}]
set_property IOSTANDARD LVCMOS18 [get_ports {ft_data[29]}]
set_property PACKAGE_PIN V7 [get_ports {ft_data[30]}]
set_property IOSTANDARD LVCMOS18 [get_ports {ft_data[30]}]
set_property PACKAGE_PIN V8 [get_ports {ft_data[31]}]
set_property IOSTANDARD LVCMOS18 [get_ports {ft_data[31]}]


set_property PACKAGE_PIN R6 [get_ports {ft_be[0]}]
set_property IOSTANDARD LVCMOS18 [get_ports {ft_be[0]}]
set_property PACKAGE_PIN T6 [get_ports {ft_be[1]}]
set_property IOSTANDARD LVCMOS18 [get_ports {ft_be[1]}]
set_property PACKAGE_PIN U6 [get_ports {ft_be[2]}]
set_property IOSTANDARD LVCMOS18 [get_ports {ft_be[2]}]
set_property PACKAGE_PIN V5 [get_ports {ft_be[3]}]
set_property IOSTANDARD LVCMOS18 [get_ports {ft_be[3]}]
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

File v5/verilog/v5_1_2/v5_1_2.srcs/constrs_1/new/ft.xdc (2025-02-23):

# ft_clk => 100000000Hz
create_clock -period 10.0 -name ft_clk_0 -waveform {0.000 5.000} [get_ports ft_clk]
set_property PACKAGE_PIN F5 [get_ports {ft_clk}]
set_property IOSTANDARD LVCMOS33 [get_ports {ft_clk}]
set_property PACKAGE_PIN F3 [get_ports {ft_rxf}]
set_property IOSTANDARD LVCMOS33 [get_ports {ft_rxf}]
set_property PACKAGE_PIN F4 [get_ports {ft_txe}]
set_property IOSTANDARD LVCMOS33 [get_ports {ft_txe}]
set_property PACKAGE_PIN B7 [get_ports {ft_data[0]}]
set_property IOSTANDARD LVCMOS33 [get_ports {ft_data[0]}]
set_property PACKAGE_PIN A7 [get_ports {ft_data[1]}]
set_property IOSTANDARD LVCMOS33 [get_ports {ft_data[1]}]
set_property PACKAGE_PIN B6 [get_ports {ft_data[2]}]
set_property IOSTANDARD LVCMOS33 [get_ports {ft_data[2]}]
set_property PACKAGE_PIN B5 [get_ports {ft_data[3]}]
set_property IOSTANDARD LVCMOS33 [get_ports {ft_data[3]}]
set_property PACKAGE_PIN C3 [get_ports {ft_data[4]}]
set_property IOSTANDARD LVCMOS33 [get_ports {ft_data[4]}]
set_property PACKAGE_PIN C2 [get_ports {ft_data[5]}]
set_property IOSTANDARD LVCMOS33 [get_ports {ft_data[5]}]
set_property PACKAGE_PIN R6 [get_ports {ft_data[6]}]
set_property IOSTANDARD LVCMOS33 [get_ports {ft_data[6]}]
set_property PACKAGE_PIN R7 [get_ports {ft_data[7]}]
set_property IOSTANDARD LVCMOS33 [get_ports {ft_data[7]}]
set_property PACKAGE_PIN C7 [get_ports {ft_data[8]}]
set_property IOSTANDARD LVCMOS33 [get_ports {ft_data[8]}]
set_property PACKAGE_PIN C6 [get_ports {ft_data[9]}]
set_property IOSTANDARD LVCMOS33 [get_ports {ft_data[9]}]
set_property PACKAGE_PIN R12 [get_ports {ft_data[10]}]
set_property IOSTANDARD LVCMOS33 [get_ports {ft_data[10]}]
set_property PACKAGE_PIN T12 [get_ports {ft_data[11]}]
set_property IOSTANDARD LVCMOS33 [get_ports {ft_data[11]}]
set_property PACKAGE_PIN T9 [get_ports {ft_data[12]}]
set_property IOSTANDARD LVCMOS33 [get_ports {ft_data[12]}]
set_property PACKAGE_PIN T10 [get_ports {ft_data[13]}]
set_property IOSTANDARD LVCMOS33 [get_ports {ft_data[13]}]
set_property PACKAGE_PIN B4 [get_ports {ft_data[14]}]
set_property IOSTANDARD LVCMOS33 [get_ports {ft_data[14]}]
set_property PACKAGE_PIN A3 [get_ports {ft_data[15]}]
set_property IOSTANDARD LVCMOS33 [get_ports {ft_data[15]}]
set_property PACKAGE_PIN G2 [get_ports {ft_be[0]}]
set_property IOSTANDARD LVCMOS33 [get_ports {ft_be[0]}]
set_property PACKAGE_PIN G1 [get_ports {ft_be[1]}]
set_property IOSTANDARD LVCMOS33 [get_ports {ft_be[1]}]
set_property PACKAGE_PIN D3 [get_ports {ft_rd}]
set_property IOSTANDARD LVCMOS33 [get_ports {ft_rd}]
set_property PACKAGE_PIN E3 [get_ports {ft_wr}]
set_property IOSTANDARD LVCMOS33 [get_ports {ft_wr}]
set_property PACKAGE_PIN E5 [get_ports {ft_oe}]
set_property IOSTANDARD LVCMOS33 [get_ports {ft_oe}]
# set_clock_groups -group [get_clocks -include_generated_clocks clk_0] \
#   -group [get_clocks -include_generated_clocks ft_clk_0] -asynchronous
set_clock_groups -async -group [get_clocks -include_generated_clocks ft_clk_0]

set_input_delay -clock [get_clocks ft_clk_0] -min -add_delay 0.000 [get_ports ft_rxf]
set_input_delay -clock [get_clocks ft_clk_0] -max -add_delay 0.001 [get_ports ft_rxf]
set_input_delay -clock [get_clocks ft_clk_0] -min -add_delay 0.000 [get_ports ft_txe]
set_input_delay -clock [get_clocks ft_clk_0] -max -add_delay 0.001 [get_ports ft_txe]
set_output_delay -clock [get_clocks ft_clk_0] -min -add_delay 0.000 [get_ports {ft_data[*]}]
set_output_delay -clock [get_clocks ft_clk_0] -max -add_delay 0.001 [get_ports {ft_data[*]}]
set_false_path -to [get_ports {ft_data[*]}]
set_output_delay -clock [get_clocks ft_clk_0] -min -add_delay 0.000 [get_ports {ft_be[*]}]
set_output_delay -clock [get_clocks ft_clk_0] -max -add_delay 0.001 [get_ports {ft_be[*]}]
set_false_path -to [get_ports {ft_be[*]}]
set_output_delay -clock [get_clocks ft_clk_0] -min -add_delay 0.000 [get_ports {ft_oe}]
set_output_delay -clock [get_clocks ft_clk_0] -max -add_delay 0.001 [get_ports {ft_oe}]
set_false_path -to [get_ports {ft_oe}]
set_output_delay -clock [get_clocks ft_clk_0] -min -add_delay 0.000 [get_ports {ft_rd}]
set_output_delay -clock [get_clocks ft_clk_0] -max -add_delay 0.001 [get_ports {ft_rd}]
set_false_path -to [get_ports {ft_rd}]
set_output_delay -clock [get_clocks ft_clk_0] -min -add_delay 0.000 [get_ports {ft_wr}]
set_output_delay -clock [get_clocks ft_clk_0] -max -add_delay 0.001 [get_ports {ft_wr}]
set_false_path -to [get_ports {ft_wr}]

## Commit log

2023-10-22 add Kicad project
    [appletini.kicad_pcb, appletini.kicad_sch, transceivers.kicad_sch]
2023-10-22 add pdf schematic
    [appletini.kicad_pcb, appletini.kicad_sch, transceivers.kicad_sch]
2023-10-22 fix some ground issues
    [appletini.kicad_pcb, appletini.kicad_sch]
2023-10-22 Changed to use single LVC07 Shrink vias to 0.6mm Spaced vias further apart Increased zone fill
    [appletini.kicad_pcb, transceivers.kicad_sch]
2023-10-22 move vias farther from pads
    [appletini.kicad_pcb]
2023-10-23 Caps on bus power lines
    [appletini.kicad_pcb, appletini.kicad_sch, transceivers.kicad_sch]
2023-10-23 remove non-routed holes from teensy footprint
    [appletini.kicad_pcb]
2023-10-23 part picks and cleanup
    [appletini.kicad_pcb, appletini.kicad_sch, transceivers.kicad_sch]
2023-10-24 Add pico reset, rotate pico to point USB up
    [appletini.kicad_pcb, appletini.kicad_sch]
2023-10-24 reduce board to 2.625in vertical
    [appletini.kicad_pcb]
2023-10-29 traces wiped
    [appletini.kicad_pcb]
2023-10-29 4 layer complete
    [appletini.kicad_pcb, appletini.kicad_sch, transceivers.kicad_sch]
2023-10-30 revisions, passed JLCPCB verification
    [appletini.kicad_pcb, appletini.kicad_sch, transceivers.kicad_sch]
2023-10-30 change Pico power from 5v to VIN
    [appletini.kicad_pcb, appletini.kicad_sch]
2023-10-30 missing ground trace on U5
    [appletini.kicad_pcb]
2023-10-31 Increased via spacing
    [appletini.kicad_pcb]
2023-11-12 draft update of pico PIO code
2023-12-30 Working v1 board and firmware
    [appletini.kicad_pcb, appletini.kicad_sch, transceivers.kicad_sch]
2024-01-27 v2 board attempt
    [Appletini_board.kicad_pcb, Appletini_board.kicad_sch, bus_transceivers.kicad_sch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]
2024-01-28 v2 board first draft done
    [Appletini_board.kicad_pcb, Appletini_board.kicad_sch, bus_transceivers.kicad_sch]
2024-01-29 pcb debugging, first draft of PIO
    [Appletini_board.kicad_pcb, Appletini_board.kicad_sch]
2024-01-31 checkpoint before lvc573 rework
    [Appletini_board.kicad_pcb, Appletini_board.kicad_sch, bus_transceivers.kicad_sch]
2024-02-03 board ordered
    [Appletini_board.kicad_pcb, Appletini_board.kicad_sch, bus_transceivers.kicad_sch]
2024-02-04 teensy code WIP
2024-03-09 V2 board working for unidirectional bus snooping
2024-03-24 fake boot for VBL detect in slot 7, fake vidhd in slot 2
2024-03-24 make fake vidhd slot choice configurable
2024-03-29 change reset detect to use RES
    [Appletini_teensy.ino, globals.h, globals.ino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]
2024-05-23 bus-to-cable card
    [bus_to_cable.kicad_pcb, bus_to_cable.kicad_sch]
2024-06-10 checkin board draft
    [appletini_board.kicad_pcb, appletini_board.kicad_sch, transceivers.kicad_sch]
2024-07-14 checkin of v4/v5
    [AppleTini_board.kicad_pcb, AppleTini_board.kicad_sch]
2024-07-15 v5 first draftw
    [AppleTini_board.kicad_pcb, AppleTini_board.kicad_sch]
2024-07-24 wip, reworking
    [AppleTini_board.kicad_pcb, AppleTini_board.kicad_sch]
2024-07-30 final v5.3
    [AppleTini_board.kicad_pcb, AppleTini_board.kicad_sch]
2024-07-31 v5 point
    [AppleTini_board.kicad_pcb, AppleTini_board.kicad_sch]
2024-08-01 v5 board order
    [AppleTini_board.kicad_pcb, AppleTini_board.kicad_sch]
2024-11-17 v5.1 Kicad design, v5.1 Alchitry design
    [AppleTini_board.kicad_pcb, AppleTini_board.kicad_sch]
